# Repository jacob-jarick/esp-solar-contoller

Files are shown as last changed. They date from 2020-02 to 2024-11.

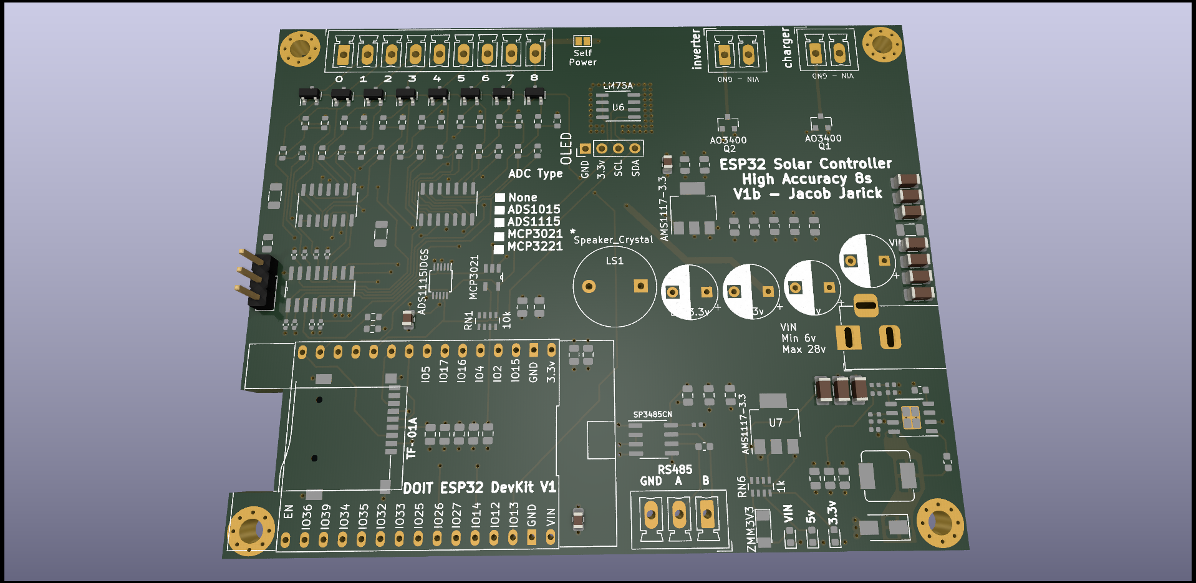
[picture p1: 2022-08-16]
esp32 board.png

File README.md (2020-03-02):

# esp-solar-contoller

esp8266 and esp32 based solar controllers targetting Houses with a fronius solar system (other inverters can be supported).

Inspired by the various DIY powerwalls

https://www.facebook.com/groups/diypowerwalls/

## Use

Common Day devices:

* Pool Pump
* powerwall / UPS / Battery Bank charger
* roof exhuast fan

Common Night time Devices:

* UPS mains disconnect
* Grid tie inverter turn on

## Example Applications

**Simple**

(day) Turn on day time device when PV export is greater than device size (eg pool pump)

**DIY Powerwall**

(Day) Turn on charger when PV export is greater than charger size.

(night) Turn on inverter when power import is larger than inverter size.

**UPS**

(Day) Turn on charger when PV export is greater than charger size.

(night) disconnect UPS mains if house is drawing power from the grid.

## Features

* Self hosted solution, no external servers needed everything runs on the microchip.
* Complete Web Interface for confguration and monitoring.
* JSON config file for easy manual editing.
* OLED display
* Support querying Fronius inverters directly
* NTP time sync
* Fallback WiFi network settings.

### Battery Monitoring (esp32)

* High voltage disconect (day)
* Low Cell Voltage disconnect (night)
* High temp shutdown

## esp8266

Supporrt for all common esp8266 boards.

* sonoff
* IoT Yunshun
* Anything tasmota runs on.

Supports adding OLED display the above.

## ESP32 Board

Custom designed board.

* 16 Bit 4 channel ADC fed to 4 8x analog signal multiplexers allowing for a total of 32 analog lines.

* 16 Voltage monitoring lines.
* 16 ntc temp sensors + 1 ambient temp sensor.
* SD Card for config storage.
* Simple Oled display.
* Piezo buzzer.
* 5v & 3.3v i2c headers for expansion.

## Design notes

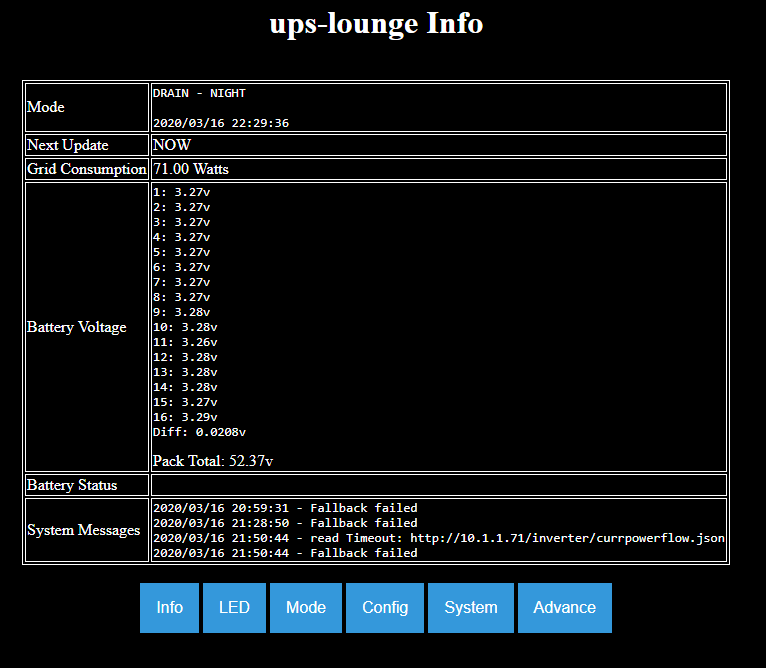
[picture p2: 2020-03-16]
pictures/stats.PNG

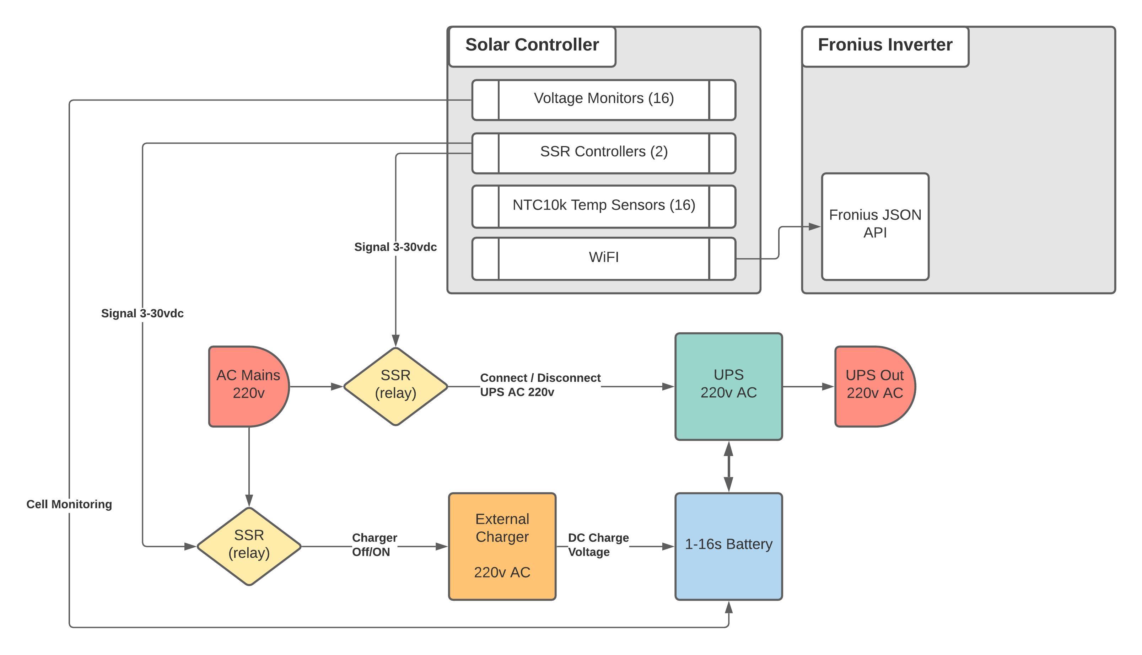
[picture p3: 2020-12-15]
docs/Solar Controller - UPS.png

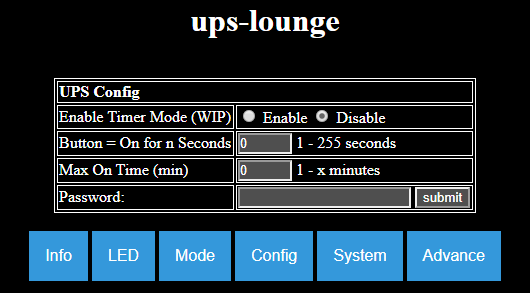
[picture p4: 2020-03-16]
pictures/timer config.PNG

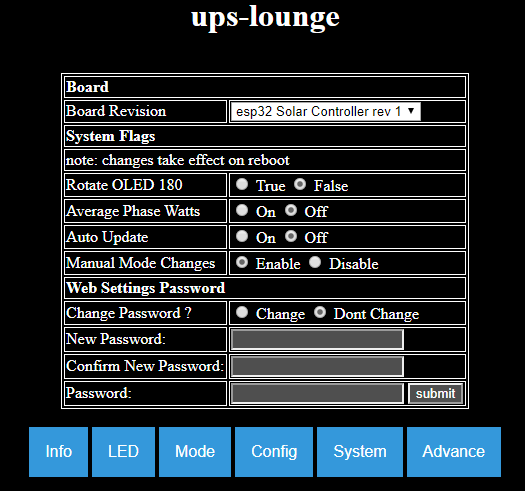
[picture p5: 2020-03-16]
pictures/system config.PNG

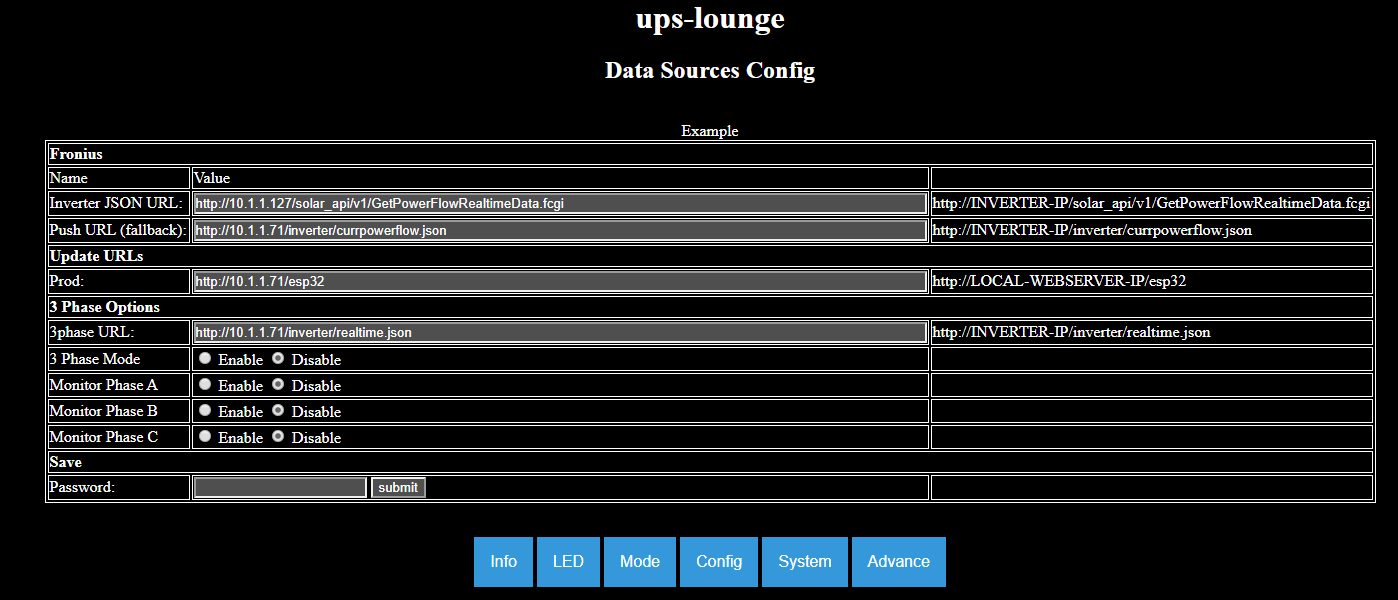
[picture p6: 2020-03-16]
pictures/data sources config.PNG

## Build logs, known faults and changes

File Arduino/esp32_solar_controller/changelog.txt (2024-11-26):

     HEAD~0	0477866 containsKey
     HEAD~1	7890894 removed jsonsize
     HEAD~2	e542fd9 no longer using DynamicJsonDocument
     HEAD~3	619b934 beep fixed !
     HEAD~4	3cfe7eb WIP
     HEAD~5	72b58d7 Updating to boards library 3.0
     HEAD~6	6bced2e migrate to board libs 3.0
     HEAD~7	af7de4d updated ansible stuff
     HEAD~8	767b9e8 Update jsonhost.yaml
     HEAD~9	dbcf0e7 esp32 board fw update, html fix
    HEAD~10	cb4bff7 HASS stuff
    HEAD~11	57f0b29 Merge branch 'master' of https://github.com/jacob-jarick/esp-solar-contoller
    HEAD~12	f5a5de1 more automation
    HEAD~13	b6dcd12 expose pin mode in api
    HEAD~14	d88c020 Update configuration.yaml
    HEAD~15	5f34a1a Update configuration.yaml
    HEAD~16	f50d760 Create JSONPath Expression Tester.url
    HEAD~17	27d5b2b Update configuration.yaml
    HEAD~18	b6071d5 added switch for HASS
    HEAD~19	deb101d home automation stuff

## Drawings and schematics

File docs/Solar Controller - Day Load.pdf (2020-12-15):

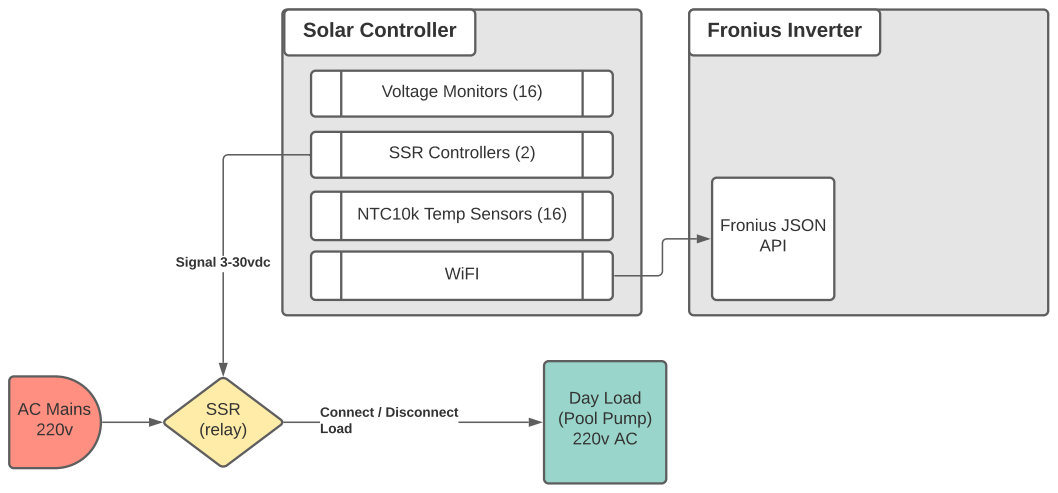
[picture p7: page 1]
Day Load (Pool Pump) 220v AC; SSR (relay); Fronius JSON API; Signal 3-30vdc; Connect / Disconnect Load; AC Mains 220v; Solar Controller; Voltage Monitors (16); SSR Controllers (2); NTC10k Temp Sensors (16); WiFI; Fronius Inverter

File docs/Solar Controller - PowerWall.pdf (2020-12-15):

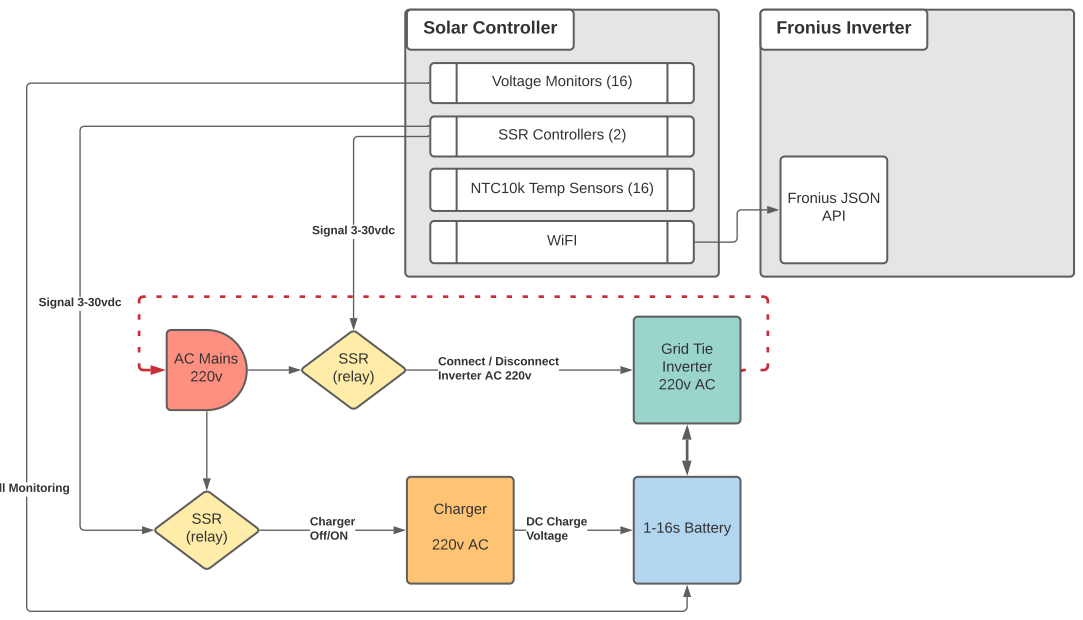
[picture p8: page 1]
Grid Tie Inverter 220v AC; SSR (relay); Fronius JSON API; Charger; 1-16s Battery; Signal 3-30vdc; DC Charge Voltage; Connect / Disconnect Inverter AC 220v; AC Mains 220v; Cell Monitoring; Solar Controller; Voltage Monitors (16); SSR Controllers (2); NTC10k Temp Sensors (16); WiFI; Fronius Inverter

Charger Off/ON

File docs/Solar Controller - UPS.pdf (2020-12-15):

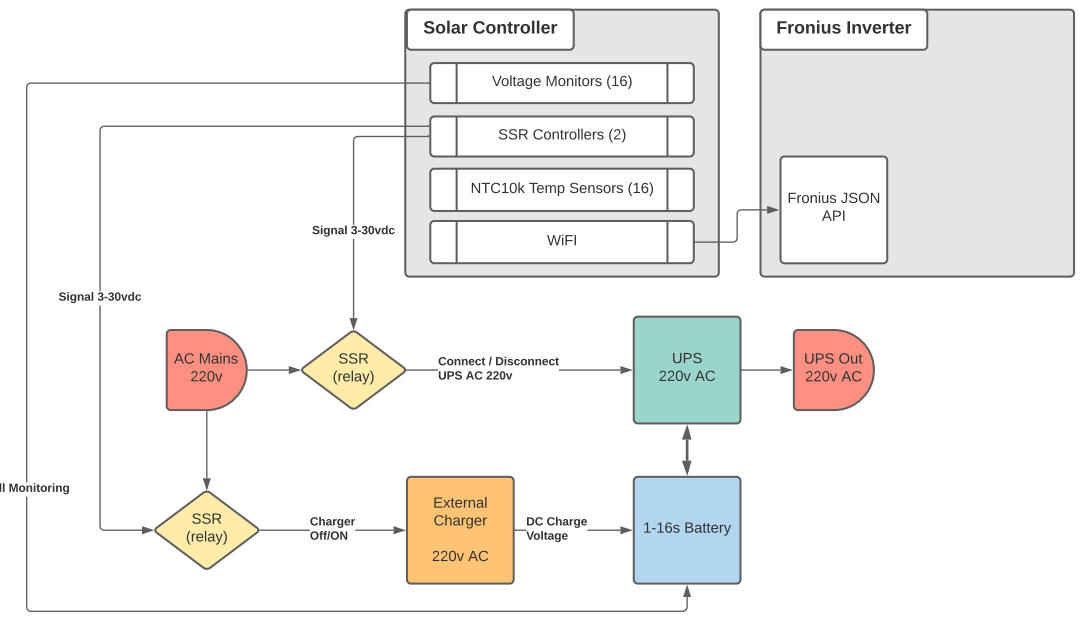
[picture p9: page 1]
UPS 220v AC; SSR (relay); Fronius JSON API; External Charger; 1-16s Battery; Signal 3-30vdc; DC Charge Voltage; Connect / Disconnect UPS AC 220v; AC Mains 220v; Cell Monitoring; UPS Out 220v AC; Solar Controller; Voltage Monitors (16); SSR Controllers (2); NTC10k Temp Sensors (16); WiFI; Fronius Inverter

Charger Off/ON

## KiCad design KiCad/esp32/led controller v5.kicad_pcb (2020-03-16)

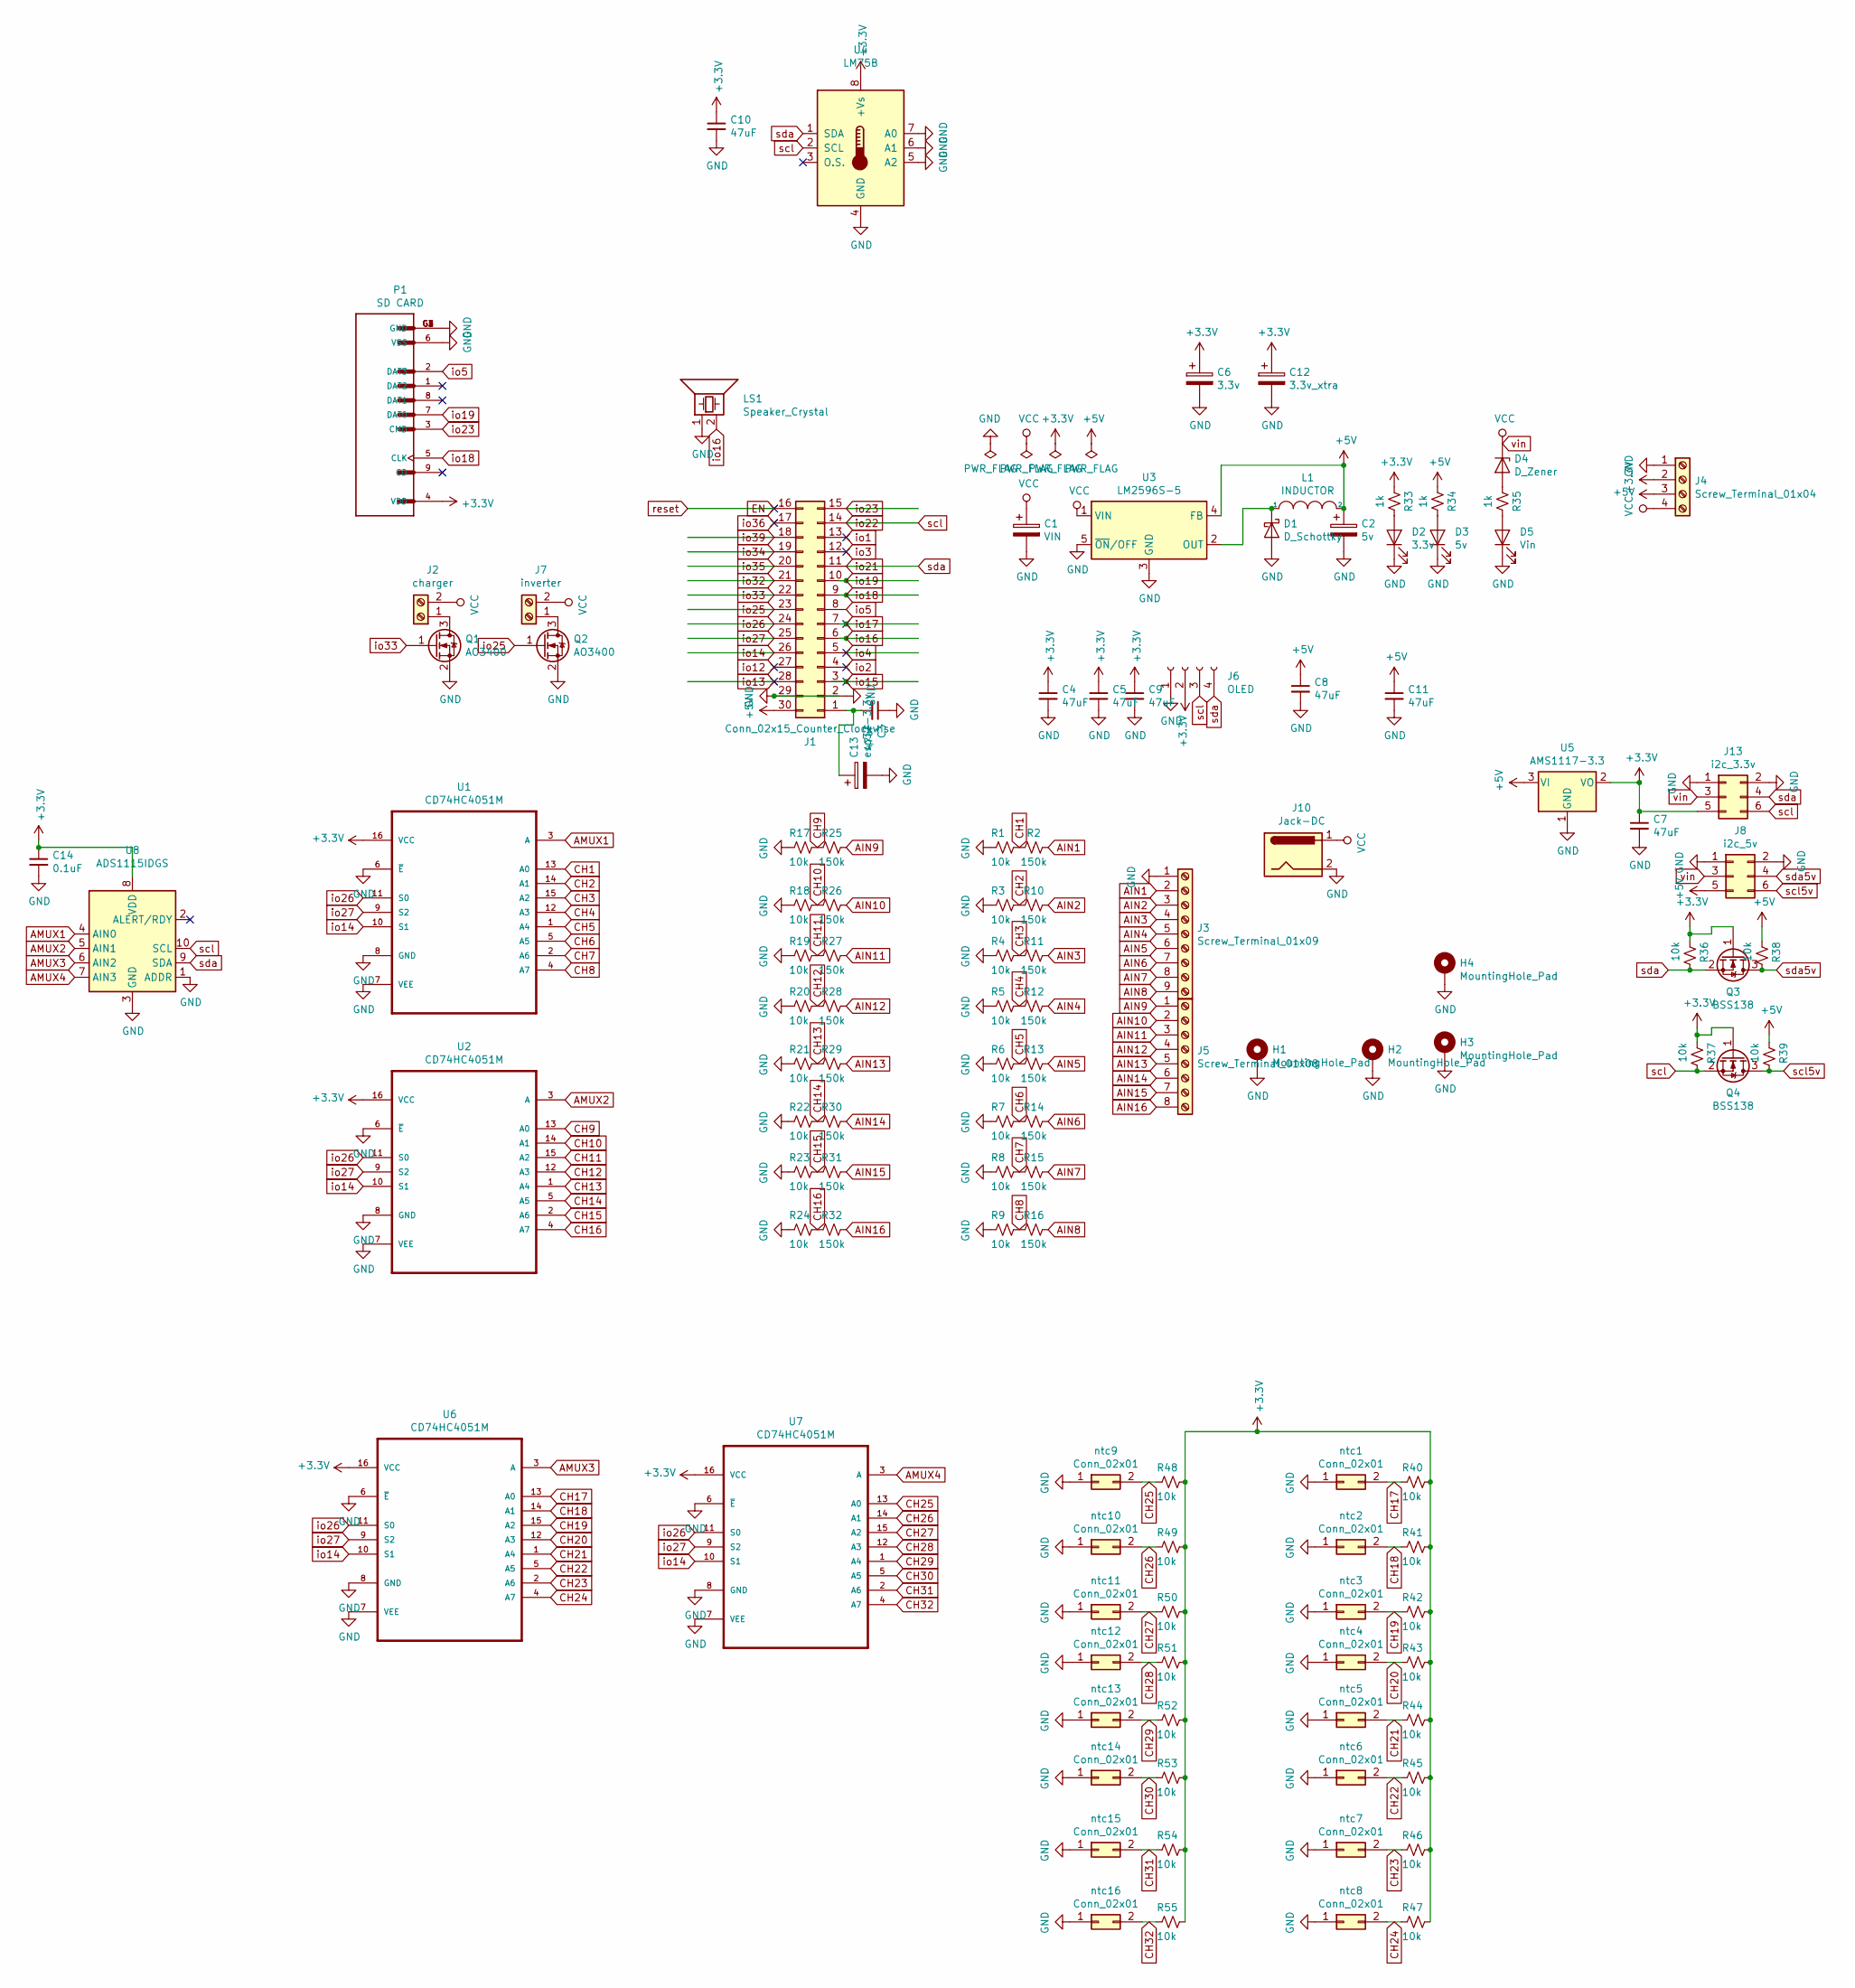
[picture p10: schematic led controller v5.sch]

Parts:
C1: VIN; CP_Radial_D10.0mm_P7.50mm
C2: 5v; CP_Radial_D10.0mm_P7.50mm
C3, C4, C5, C7, C8, C9, C10, C11: 47uF; C_0805_2012Metric_Pad1.15x1.40mm_HandSolder
C6: 3.3v; CP_Radial_D10.0mm_P7.50mm
C12: 3.3v_xtra; CP_Radial_D10.0mm_P7.50mm
C13: esp32-3.3v; CP_Radial_D10.0mm_P7.50mm
C14: 0.1uF; C_0805_2012Metric_Pad1.15x1.40mm_HandSolder
D1: D_Schottky; D_SMA_Handsoldering
D2: 3.3v; LED_1206_3216Metric_Pad1.42x1.75mm_HandSolder
D3: 5v; LED_1206_3216Metric_Pad1.42x1.75mm_HandSolder
D4: D_Zener; D_SOD-323F
D5: Vin; LED_1206_3216Metric_Pad1.42x1.75mm_HandSolder
H1, H2, H3, H4: MountingHole_Pad; MountingHole_3.2mm_M3_Pad_Via
J1: Conn_02x15_Counter_Clockwise; esp32-devkit-v1
J2: charger; PhoenixContact_MCV_1,5_2-G-3.81_1x02_P3.81mm_Vertical
J3: Screw_Terminal_01x09; PhoenixContact_MCV_1,5_9-G-3.81_1x09_P3.81mm_Vertical
J4: Screw_Terminal_01x04; PhoenixContact_MCV_1,5_4-G-3.81_1x04_P3.81mm_Vertical
J5: Screw_Terminal_01x08; PhoenixContact_MCV_1,5_8-G-3.81_1x08_P3.81mm_Vertical
J6: OLED; PinHeader_1x04_P2.54mm_Vertical
J7: inverter; PhoenixContact_MCV_1,5_2-G-3.81_1x02_P3.81mm_Vertical
J8: i2c_5v; i2c-Header-5v
J10: Jack-DC; BarrelJack_Horizontal
J13: i2c_3.3v; i2c-Header
L1: INDUCTOR; L_Taiyo-Yuden_MD-5050
LS1: Speaker_Crystal; Buzzer_15x7.5RM7.6
P1: SD CARD; SUNTECH_ST-TF-003A
Q1, Q2: AO3400; SOT-23
Q3, Q4: BSS138; SOT-23
R1, R3, R4, R5, R6, R7, R8, R9, R17, R18, R19, R20, R21, R22, R23, R24, R36, R37, R38, R39, R40, R41, R42, R43, R44, R45, R46, R47, R48, R49, R50, R51, R52, R53, R54, R55: 10k; R_0805_2012Metric_Pad1.15x1.40mm_HandSolder
R2, R10, R11, R12, R13, R14, R15, R16, R25, R26, R27, R28, R29, R30, R31, R32: 150k; R_0805_2012Metric_Pad1.15x1.40mm_HandSolder
R33, R34, R35: 1k; R_0805_2012Metric_Pad1.15x1.40mm_HandSolder
U1, U2, U6, U7: CD74HC4051M; STC_SOP-16_3.9x9.9mm_P1.27mm
U3: LM2596S-5; TO-263-5_TabPin3
U4: LM75B; SOIC-8_3.9x4.9mm_P1.27mm
U5: AMS1117-3.3; SOT-223-3_TabPin2
U8: ADS1115IDGS; TSSOP-10_3x3mm_P0.5mm
ntc1, ntc2, ntc3, ntc4, ntc5, ntc6, ntc7, ntc8, ntc9, ntc10, ntc11, ntc12, ntc13, ntc14, ntc15, ntc16: Conn_02x01; PinHeader_1x02_P2.54mm_Vertical

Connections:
+3V3: C4.1, C5.1, C6.1, C7.1, C9.1, C10.1, C12.1, C14.1, J4.2, J6.2, J13.5, P1.4 (VDD), Q3.1 (G), Q4.1 (G), R33.1, R36.2, R37.2, R40.1, R41.1, R42.1, R43.1, R44.1, R45.1, R46.1, R47.1, R48.1, R49.1, R50.1, R51.1, R52.1, R53.1, R54.1, R55.1, U1.16 (VCC), U2.16 (VCC), U4.8 (+Vs), U5.2 (VO), U6.16 (VCC), U7.16 (VCC), U8.8 (VDD)
+5V: C2.1, C8.1, C11.1, J1.30, J4.3, J8.5, L1.2, R34.1, R38.2, R39.2, U3.4 (FB), U5.3 (VI)
AIN1: J3.2, R2.2
AIN2: J3.3, R10.2
AIN3: J3.4, R11.2
AIN4: J3.5, R12.2
AIN5: J3.6, R13.2
AIN6: J3.7, R14.2
AIN7: J3.8, R15.2
AIN8: J3.9, R16.2
AIN9: J5.1, R25.2
AIN10: J5.2, R26.2
AIN11: J5.3, R27.2
AIN12: J5.4, R28.2
AIN13: J5.5, R29.2
AIN14: J5.6, R30.2
AIN15: J5.7, R31.2
AIN16: J5.8, R32.2
AMUX1: U1.3 (A), U8.4 (AIN0)
AMUX2: U2.3 (A), U8.5 (AIN1)
AMUX3: U6.3 (A), U8.6 (AIN2)
AMUX4: U7.3 (A), U8.7 (AIN3)
CH1: R1.1, R2.1, U1.13 (A0)
CH2: R3.1, R10.1, U1.14 (A1)
CH3: R4.1, R11.1, U1.15 (A2)
CH4: R5.1, R12.1, U1.12 (A3)
CH5: R6.1, R13.1, U1.1 (A4)
CH6: R7.1, R14.1, U1.5 (A5)
CH7: R8.1, R15.1, U1.2 (A6)
CH8: R9.1, R16.1, U1.4 (A7)
CH9: R17.1, R25.1, U2.13 (A0)
CH10: R18.1, R26.1, U2.14 (A1)
CH11: R19.1, R27.1, U2.15 (A2)
CH12: R20.1, R28.1, U2.12 (A3)
CH13: R21.1, R29.1, U2.1 (A4)
CH14: R22.1, R30.1, U2.5 (A5)
CH15: R23.1, R31.1, U2.2 (A6)
CH16: R24.1, R32.1, U2.4 (A7)
CH17: R40.2, U6.13 (A0), ntc1.2
CH18: R41.2, U6.14 (A1), ntc2.2
CH19: R42.2, U6.15 (A2), ntc3.2
CH20: R43.2, U6.12 (A3), ntc4.2
CH21: R44.2, U6.1 (A4), ntc5.2
CH22: R45.2, U6.5 (A5), ntc6.2
CH23: R46.2, U6.2 (A6), ntc7.2
CH24: R47.2, U6.4 (A7), ntc8.2
CH25: R48.2, U7.13 (A0), ntc9.2
CH26: R49.2, U7.14 (A1), ntc10.2
CH27: R50.2, U7.15 (A2), ntc11.2
CH28: R51.2, U7.12 (A3), ntc12.2
CH29: R52.2, U7.1 (A4), ntc13.2
CH30: R53.2, U7.5 (A5), ntc14.2
CH31: R54.2, U7.2 (A6), ntc15.2
CH32: R55.2, U7.4 (A7), ntc16.2
EN: J1.16
GND: C1.2, C2.2, C3.1, C4.2, C5.2, C6.2, C7.2, C8.2, C9.2, C10.2, C11.2, C12.2, C13.2, C14.2, D1.2 (A), D2.1 (K), D3.1 (K), D5.1 (K), H1.1, H2.1, H3.1, H4.1, J1.2, J1.29, J3.1, J4.1, J6.1, J8.1, J8.2, J10.2, J13.1, J13.2, LS1.1, P1.6 (VSS), P1.G1 (GND), P1.G2 (GND), P1.G3 (GND), P1.G4 (GND), Q1.2 (S), Q2.2 (S), R1.2, R3.2, R4.2, R5.2, R6.2, R7.2, R8.2, R9.2, R17.2, R18.2, R19.2, R20.2, R21.2, R22.2, R23.2, R24.2, U1.6 (~E), U1.7 (VEE), U1.8 (GND), U2.6 (~E), U2.7 (VEE), U2.8 (GND), U3.3 (GND), U3.5 (~ON~/OFF), U4.4 (GND), U4.5 (A2), U4.6 (A1), U4.7 (A0), U5.1 (GND), U6.6 (~E), U6.7 (VEE), U6.8 (GND), U7.6 (~E), U7.7 (VEE), U7.8 (GND), U8.1 (ADDR), U8.3 (GND), ntc1.1, ntc2.1, ntc3.1, ntc4.1, ntc5.1, ntc6.1, ntc7.1, ntc8.1, ntc9.1, ntc10.1, ntc11.1, ntc12.1, ntc13.1, ntc14.1, ntc15.1, ntc16.1
unnamed: C3.2, C13.1, J1.1
unnamed: D1.1 (K), L1.1, U3.2 (OUT)
unnamed: D2.2 (A), R33.2
unnamed: D3.2 (A), R34.2
unnamed: D4.2 (A), R35.1
unnamed: D5.2 (A), R35.2
unnamed: J2.1, Q1.3 (D)
unnamed: J7.1, Q2.3 (D)
io1: J1.13
io2: J1.4
io3: J1.12
io4: J1.5
io5: J1.8, P1.2 (DAT3)
io12: J1.27
io13: J1.28
io14: J1.26, U1.10 (S1), U2.10 (S1), U6.10 (S1), U7.10 (S1)
io15: J1.3
io16: J1.6, LS1.2
io17: J1.7
io18: J1.9, P1.5 (CLK)
io19: J1.10, P1.7 (DAT0)
io21: J1.11, J6.4, J13.4, Q3.2 (S), R36.1, U4.1 (SDA), U8.9 (SDA)
io22: J1.14, J6.3, J13.6, Q4.2 (S), R37.1, U4.2 (SCL), U8.10 (SCL)
io23: J1.15, P1.3 (CMD)
io25: J1.23, Q2.1 (G)
io26: J1.24, U1.11 (S0), U2.11 (S0), U6.11 (S0), U7.11 (S0)
io27: J1.25, U1.9 (S2), U2.9 (S2), U6.9 (S2), U7.9 (S2)
io32: J1.21
io33: J1.22, Q1.1 (G)
io34: J1.19
io35: J1.20
io36: J1.17
io39: J1.18
scl5v: J8.6, Q4.3 (D), R39.1
sda5v: J8.4, Q3.3 (D), R38.1
vin: C1.1, D4.1 (K), J2.2, J4.4, J7.2, J8.3, J10.1, J13.3, U3.1 (VIN)

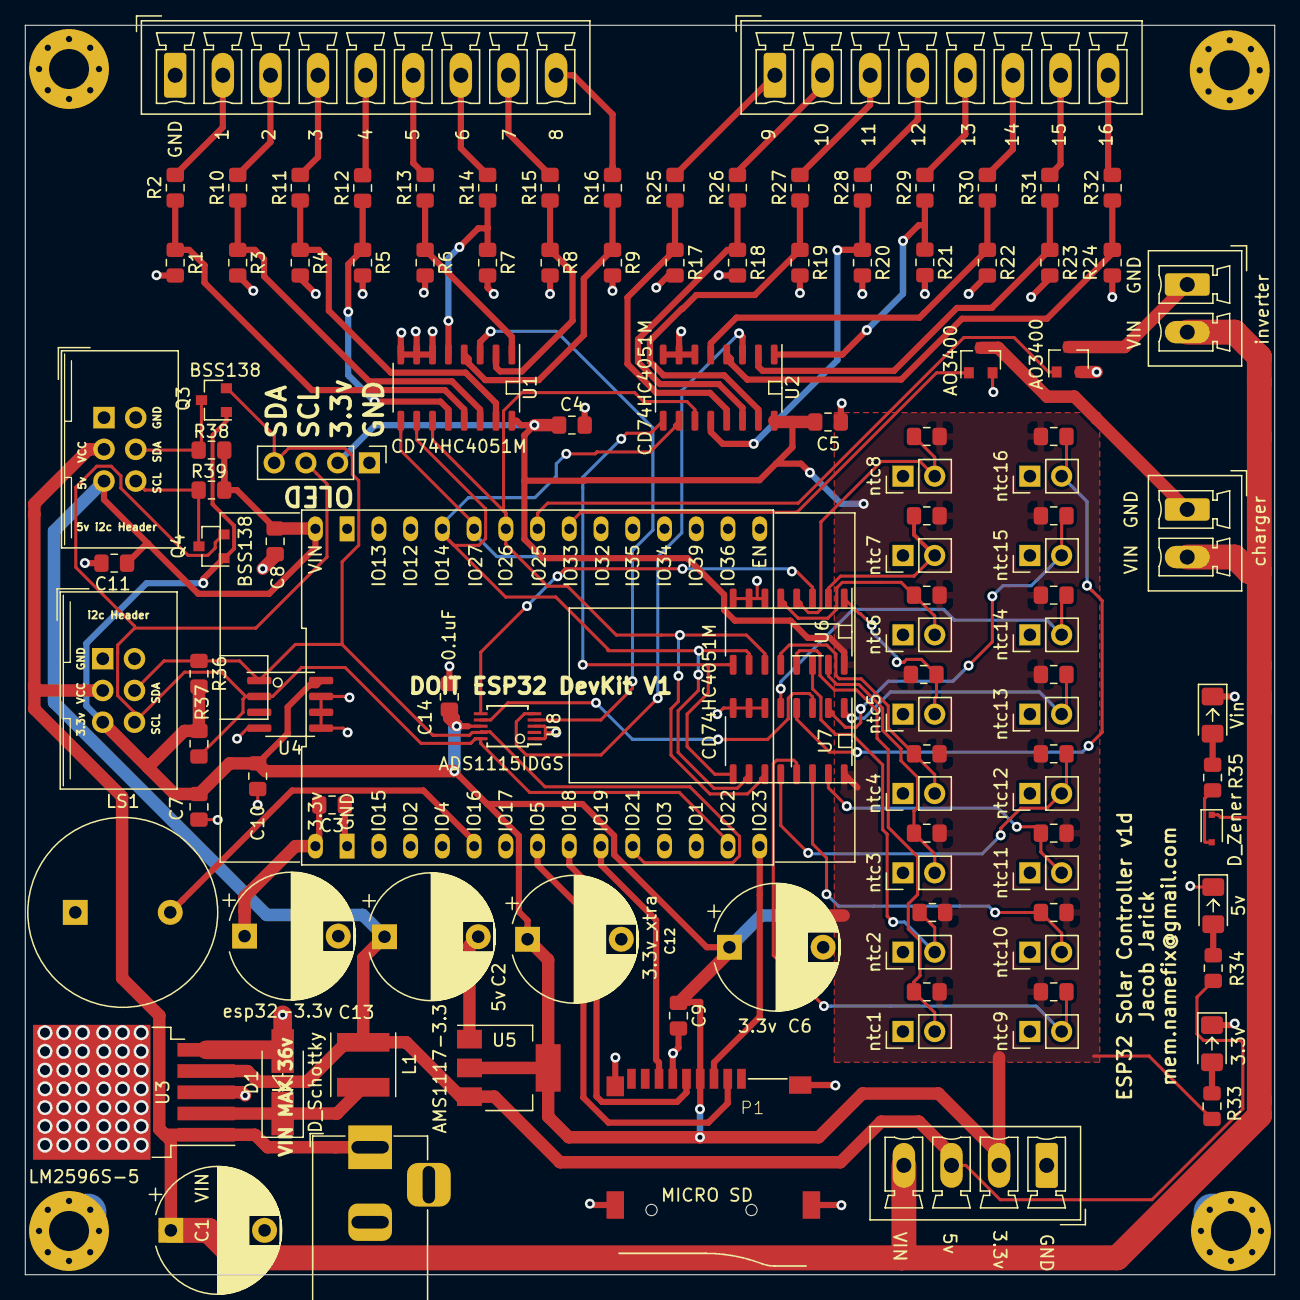
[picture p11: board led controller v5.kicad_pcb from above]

Board: 2 copper layers, 100.0 x 100.0 mm, 119 parts (0 on the bottom side), 78 nets.

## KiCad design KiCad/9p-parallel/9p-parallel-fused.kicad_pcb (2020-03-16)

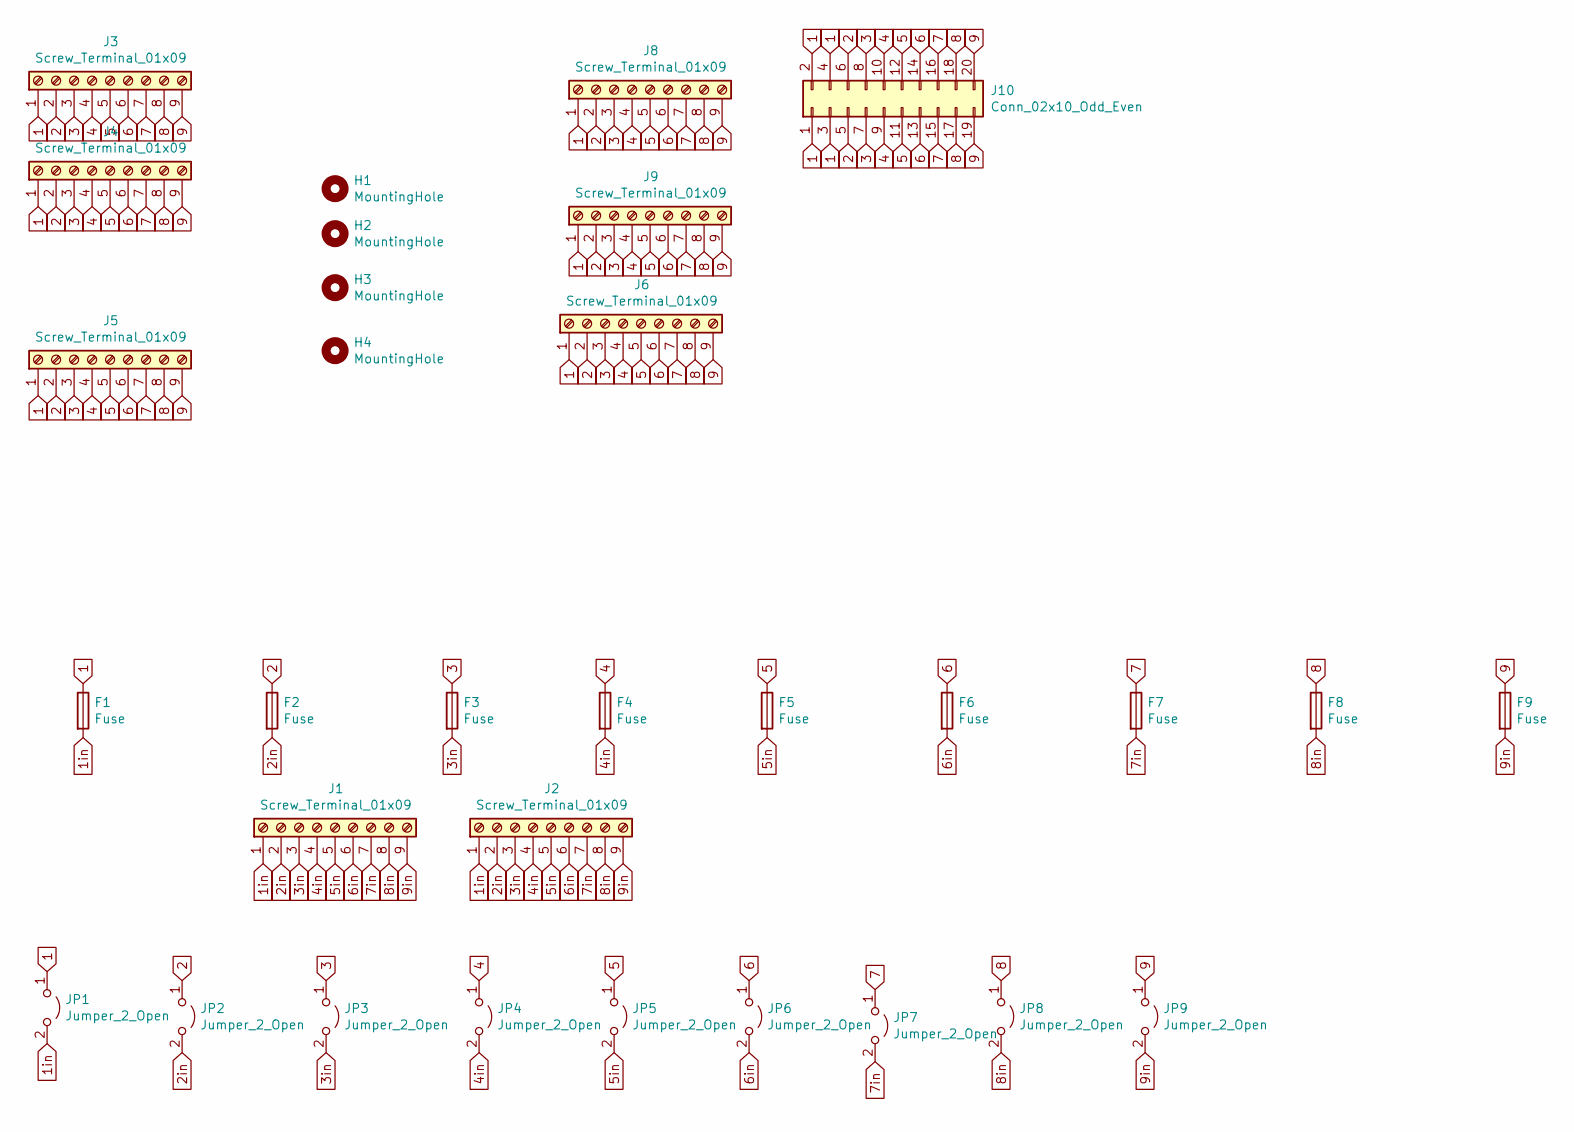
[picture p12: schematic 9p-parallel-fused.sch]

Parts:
F1, F2, F3, F4, F5, F6, F7, F8, F9: Fuse; Fuseholder_Cylinder-5x20mm_Stelvio-Kontek_PTF78_Horizontal_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
H1, H2, H3, H4: MountingHole; MountingHole_4.3mm_M4_ISO14580
J1: Screw_Terminal_01x09; PhoenixContact_MC_1,5_9-G-5.08_1x09_P5.08mm_Horizontal-larg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
J2, J6, J8, J9: Screw_Terminal_01x09; PhoenixContact_MCV_1,5_9-G-3.81_1x09_P3.81mm_Vertical
J3, J4, J5: Screw_Terminal_01x09; PhoenixContact_MCV_1,5_9-G-5.08_1x09_P5.08mm_Vertical-large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
J10: Conn_02x10_Odd_Even; IDC-Header_2x10_P2.54mm_Vertical
JP1, JP2, JP3, JP4, JP5, JP6, JP7, JP8, JP9: Jumper_2_Open; SolderJumper-2_P1.3mm_Open_Pad1.0x1.5mm

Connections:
1: F1.1, J3.1, J4.1, J5.1, J6.1, J8.1, J9.1, J10.1, J10.2, J10.3, J10.4, JP1.1 (A)
1in: F1.2, J1.1, J2.1, JP1.2 (B)
2: F2.1, J3.2, J4.2, J5.2, J6.2, J8.2, J9.2, J10.5, J10.6, JP2.1 (A)
2in: F2.2, J1.2, J2.2, JP2.2 (B)
3: F3.1, J3.3, J4.3, J5.3, J6.3, J8.3, J9.3, J10.7, J10.8, JP3.1 (A)
3in: F3.2, J1.3, J2.3, JP3.2 (B)
4: F4.1, J3.4, J4.4, J5.4, J6.4, J8.4, J9.4, J10.9, J10.10, JP4.1 (A)
4in: F4.2, J1.4, J2.4, JP4.2 (B)
5: F5.1, J3.5, J4.5, J5.5, J6.5, J8.5, J9.5, J10.11, J10.12, JP5.1 (A)
5in: F5.2, J1.5, J2.5, JP5.2 (B)
6: F6.1, J3.6, J4.6, J5.6, J6.6, J8.6, J9.6, J10.13, J10.14, JP6.1 (A)
6in: F6.2, J1.6, J2.6, JP6.2 (B)
7: F7.1, J3.7, J4.7, J5.7, J6.7, J8.7, J9.7, J10.15, J10.16, JP7.1 (A)
7in: F7.2, J1.7, J2.7, JP7.2 (B)
8: F8.1, J3.8, J4.8, J5.8, J6.8, J8.8, J9.8, J10.17, J10.18, JP8.1 (A)
8in: F8.2, J1.8, J2.8, JP8.2 (B)
9: F9.1, J3.9, J4.9, J5.9, J6.9, J8.9, J9.9, J10.19, J10.20, JP9.1 (A)
9in: F9.2, J1.9, J2.9, JP9.2 (B)

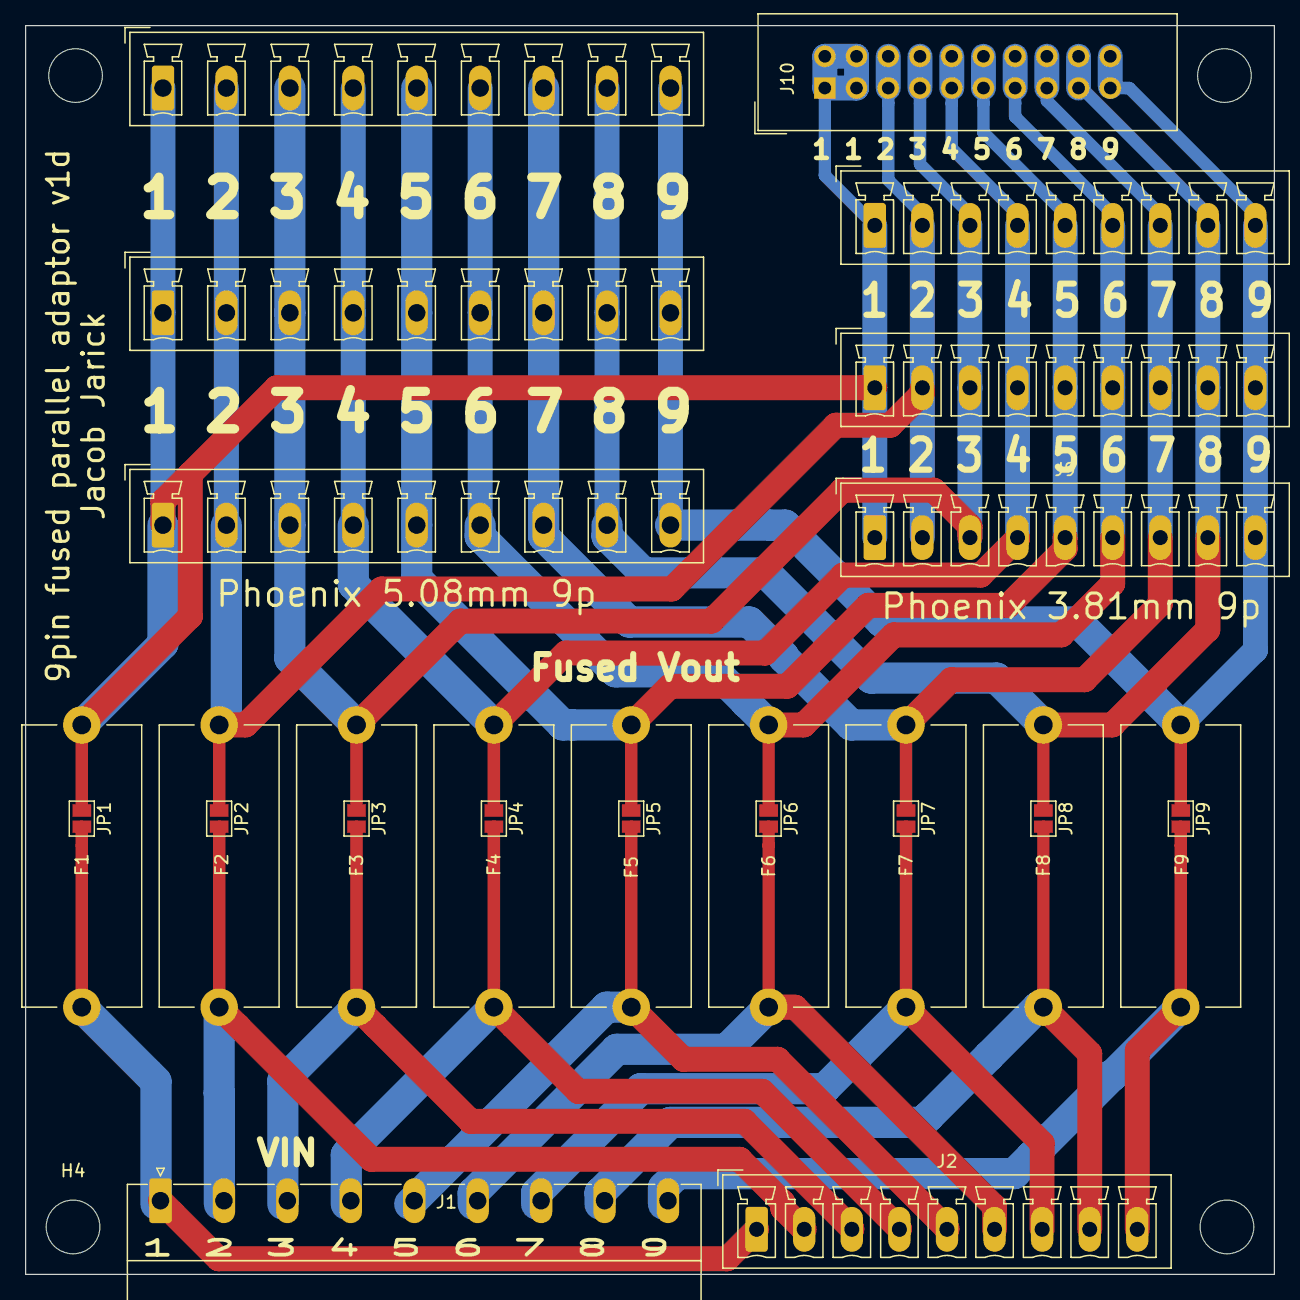
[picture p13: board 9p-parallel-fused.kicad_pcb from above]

Board: 2 copper layers, 100.0 x 100.0 mm, 31 parts (0 on the bottom side), 18 nets.

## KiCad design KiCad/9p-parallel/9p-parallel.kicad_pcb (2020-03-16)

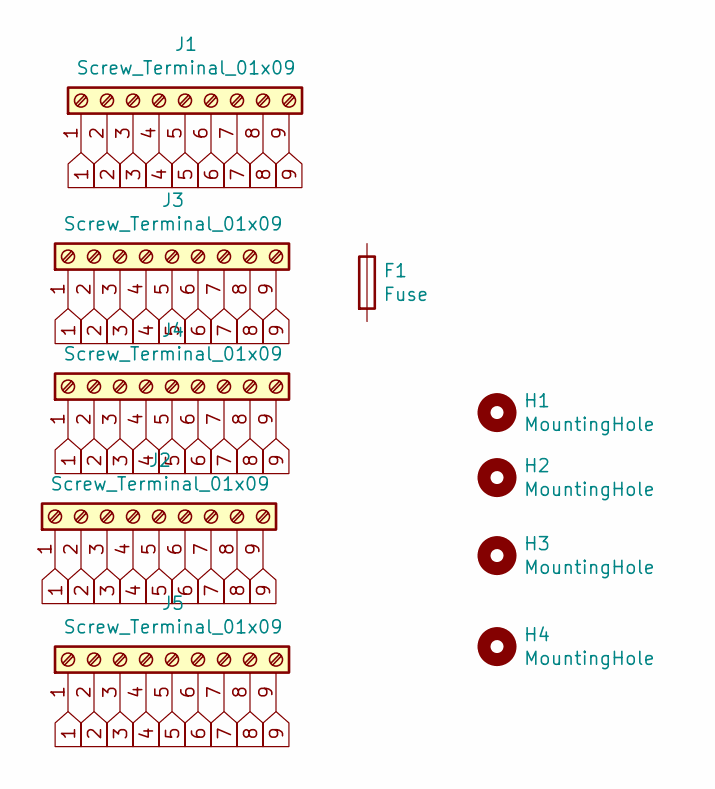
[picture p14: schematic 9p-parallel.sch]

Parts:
F1: Fuse; Fuseholder_Cylinder-5x20mm_Stelvio-Kontek_PTF78_Horizontal_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
H1, H2, H3, H4: MountingHole; MountingHole_4.3mm_M4_ISO14580
J1: Screw_Terminal_01x09; PhoenixContact_MC_1,5_9-G-5.08_1x09_P5.08mm_Horizontal
J2, J3, J4, J5: Screw_Terminal_01x09; PhoenixContact_MCV_1,5_9-G-5.08_1x09_P5.08mm_Vertical

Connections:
1: J1.1, J2.1, J3.1, J4.1, J5.1
2: J1.2, J2.2, J3.2, J4.2, J5.2
3: J1.3, J2.3, J3.3, J4.3, J5.3
4: J1.4, J2.4, J3.4, J4.4, J5.4
5: J1.5, J2.5, J3.5, J4.5, J5.5
6: J1.6, J2.6, J3.6, J4.6, J5.6
7: J1.7, J2.7, J3.7, J4.7, J5.7
8: J1.8, J2.8, J3.8, J4.8, J5.8
9: J1.9, J2.9, J3.9, J4.9, J5.9

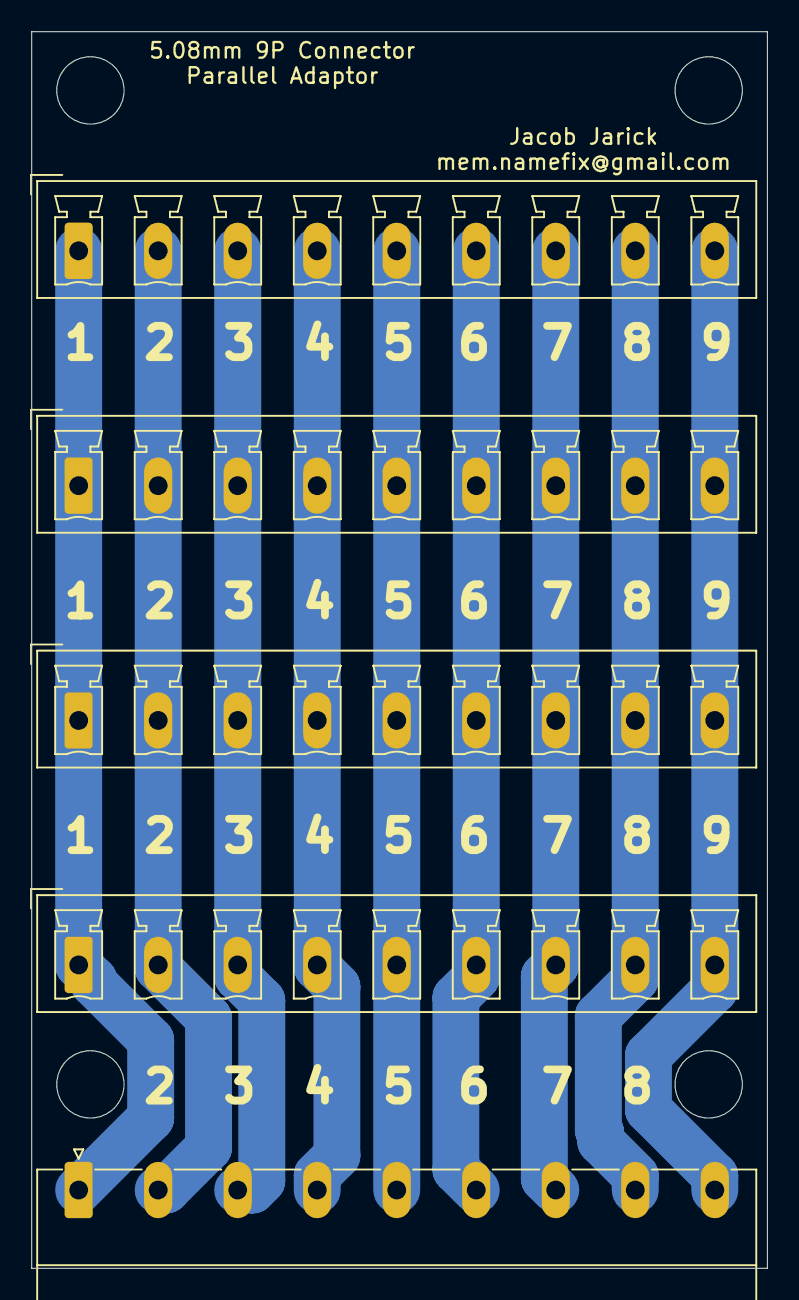
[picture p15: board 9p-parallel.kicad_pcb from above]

Board: 2 copper layers, 47.0 x 79.0 mm, 9 parts (0 on the bottom side), 9 nets.

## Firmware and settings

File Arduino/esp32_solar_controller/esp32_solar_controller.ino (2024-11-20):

/*

Note I use esp32 doit dev kit v1.
but the arduino IDE settings for this board seem to cause issues.

so I configure the IDE to use:

* WEMOS LOLIN32
* Patition Scheme: Minimal SPIFFS, large app with OTA
* CPU 240Mhz (WiFi/BT)
* Flash Frequency 80Mhz

this seems to resolve OTA issues.

*/

#define FW_VERSION 406

// to longer timeout = esp weirdness
#define httpget_timeout 5000

#define OPT_DISABLE -2
#define OPT_DEFAULT -1

#define stiny 32
#define ssmall 64
#define smedium 128
#define slarge 257

#define MAX_CELLS 16


// ================================================================================================
/*
 *  Print last reset reason of ESP32
 *  =================================
 *
 *  Use either of the methods print_reset_reason
 *  or verbose_print_reset_reason to display the
 *  cause for the last reset of this device.
 *
 *  Public Domain License.
 *
 *  Author:
 *  Evandro Luis Copercini - 2017
 */

#if CONFIG_IDF_TARGET_ESP32  // ESP32/PICO-D4
#include "esp32/rom/rtc.h"
#elif CONFIG_IDF_TARGET_ESP32S2
#include "esp32s2/rom/rtc.h"
#elif CONFIG_IDF_TARGET_ESP32C2
#include "esp32c2/rom/rtc.h"
#elif CONFIG_IDF_TARGET_ESP32C3
#include "esp32c3/rom/rtc.h"
#elif CONFIG_IDF_TARGET_ESP32S3
#include "esp32s3/rom/rtc.h"
#elif CONFIG_IDF_TARGET_ESP32C6
#include "esp32c6/rom/rtc.h"
#elif CONFIG_IDF_TARGET_ESP32H2
#include "esp32h2/rom/rtc.h"
#else
#error Target CONFIG_IDF_TARGET is not supported
#endif

#define uS_TO_S_FACTOR 1000000 /* Conversion factor for micro seconds to seconds */

// ================================================================================================

// #include <Arduino.h>
#include <SD.h>

#include <WiFi.h>
#include <WiFiClient.h>
#include <WiFiAP.h> // todo remove as WiFi is configured via SD card json config
#include <WiFiUdp.h>
#include <ESPmDNS.h>

#include <HTTPClient.h>

#include <ESP32httpUpdate.h>

#include <ArduinoJson.h>

#include <WebServer.h>
WebServer server(80);

// -----------------------------------------------------------------------------------------

#include <Wire.h>
#include "SSD1306Ascii.h"
#include "SSD1306AsciiWire.h"

SSD1306AsciiWire oled;

// -----------------------------------------------------------------------------------------

#include <Ads1115_mux.h>
const uint8_t pin_asel1 = 26;
const uint8_t pin_asel2 = 17;
const uint8_t pin_asel3 = 14;
const uint8_t pin_asel4 = 27;

Ads1115_mux adsmux(pin_asel1, pin_asel2, pin_asel3, pin_asel4);

// -----------------------------------------------------------------------------------------

const uint8_t pin_buzzer = 16;

// -----------------------------------------------------------------------------------------
// lm75a

// note: modify library and comment out wire.begin and wire.end

#include <M2M_LM75A.h>
M2M_LM75A lm75a(0x4f);
M2M_LM75A lm75a2(0x48); // used on micro boards

uint8_t lm75a_address = 0x4f;

float board_temp = 0;
float board_temp_min = 9999999;
float board_temp_max = 0;
float board_temp_old = 0; // only used to track changes in temp to prevent message spam.

// -----------------------------------------------------------------------------------------

#include <Mmaths.h>

Mmaths mmaths;

// -----------------------------------------------------------------------------------------

#include <TimeLib.h>

const unsigned int localPort = 2390;      // local port to listen for UDP packets

const int NTP_PACKET_SIZE = 48; // NTP time is in the first 48 bytes of message
byte packetBuffer[NTP_PACKET_SIZE]; //buffer to hold incoming & outgoing packets

WiFiUDP Udp;

// -----------------------------------------------------------------------------------------
// timers

struct SysTimers
{
  unsigned long api = 0;
  unsigned long iapi = 0;
  unsigned long api_last_update = 0;

  unsigned long mode_check = 0;
  unsigned long pgrid_last_update = 0;
  unsigned long use_fallback = 0;

  unsigned long lv_shutdown = 0;
  unsigned long hv_shutdown = 0;

  unsigned long charger_off = 0;
  unsigned long inverter_off = 0;

  unsigned long pgrid = 0;
  unsigned long adc_poll = 0;
  unsigned long lm75a_poll = 0;

  unsigned long update_check = 0;
  unsigned long ntp_sync = 0;
  unsigned long oled = 0;

  unsigned long led = 0;

  unsigned long i2c_check = 0;

  unsigned long calc_energy_usage = 0;
};

SysTimers timers;

//------------------------------------------------------------------------------
// cell voltages

double cells_volts[MAX_CELLS*3];
double cells_volts_real[MAX_CELLS*3]; // used to track real voltage when using AIN, used as temp storage for API
float cell_volt_diff = 0;
float cell_volt_high = 0;
float cell_volt_low = 0;

float pack_total_volts = 0;

// uint8_t cell_lh[2] = {0, 0};
uint8_t low_cell = 0;
uint8_t high_cell = 0;

//------------------------------------------------------------------------------

uint8_t vapi_errors = 0;

//------------------------------------------------------------------------------

const String mime_html    = "text/html";
const String mime_txt     = "text/plain";
const String mime_json    = "application/json";
const String mime_css     = "text/css";

const String http_str     = "http://";
const String denied_str   = "Denied";
const String title_str    = "title_hostn";

const String dothtml        = ".htm";
const String dottxt        = ".txt";

const String html_header          = "/header" + dothtml;
const String html_config          = "/config" + dothtml;
const String html_battery         = "/batconf" + dothtml;
const String html_calibrate       = "/batcal" + dothtml;
const String html_acinfo          = "/acinfo" + dothtml;
const String html_cpconfig        = "/cpconfig" + dothtml;
const String html_stats           = "/stats" + dothtml;
const String html_mode            = "/mode" + dothtml;
const String html_modet            = "/modet" + dothtml;
const String html_apiservers      = "/api" + dothtml;
const String html_advance_config  = "/advance" + dothtml;
const String html_footer          = "/footer" + dothtml;
const String html_js_header       = "/jsheader" + dothtml;
const String html_issue_log       = "/issue" + dothtml;
const String html_net_config      = "/network" + dothtml;
const String html_datasrcs        = "/datasrcs" + dothtml;
const String html_sys_info        = "/system" + dothtml;
const String html_battery_info    = "/battery" + dothtml;
const String html_upload_config   = "/up_conf" + dothtml;
const String html_port_config     = "/portconf" + dothtml;

const String css_file             = "/style.css";
const String txt_log_system       = "/log" + dottxt;
const String txt_passwd_file      = "/passwd";
const String json_config_file     = "/config.jsn";

//------------------------------------------------------------------------------

const uint16_t size_system_msgs = 1024;
String system_msgs = "";



float phase_a_watts = 0;
float phase_b_watts = 0;
float phase_c_watts = 0;

float phase_a_voltage = 0;
float phase_b_voltage = 0;
float phase_c_voltage = 0;

float phase_a_voltage_high = 0;
float phase_b_voltage_high = 0;
float phase_c_voltage_high = 0;

float phase_a_voltage_low = 10000;
float phase_b_voltage_low = 10000;
float phase_c_voltage_low = 10000;


float energy_consumed_old = 0; // previous day
float energy_consumed = 0;

float phase_sum = 0;
float phase_sum_old = 0;

float phase_avg = 0;

String passwd = "";

uint8_t download_index = 0; // html page download index
byte system_mode = 0;

uint8_t i2cdevcount = 0; // used on startup and then for system i2c ping

const int8_t power_array_size = 10;

int get_url_code; // global url fetch code, eg 404, 401, 200

// =================================================================================================


//------------------------------------------------------------------------------

const uint8_t max_api_vservers = 3;
const uint8_t max_api_iservers = 1;

struct Sconfig
{
  uint16_t fwver = 0;

  float maxsystemtemp = 40;


  // API

  uint8_t api_vserver_count = 0;


  bool api_venable[max_api_vservers];
  char api_vserver_hostname[max_api_vservers][ssmall];

  bool api_ienable[max_api_iservers];
  char api_iserver_hostname[max_api_iservers][ssmall];

  bool api_lm75a = 0;
  bool api_grid = 0;

  float api_pollsecs = 1;

  // END of API

  char threephase_direct_url[smedium];
  char fronius_push_url[smedium];
  char pub_url[smedium];

  // sortme

  float lv_shutdown_delay; // float because we use fraction of hours eh 0.5h
  float hv_shutdown_delay;

  uint8_t charger_oot_min;
  uint8_t charger_oot_sec;

  uint8_t charger_off_min;
  uint8_t charger_off_sec;

  uint8_t inverter_oot_min;
  uint8_t inverter_oot_sec;
  byte cell_count;
  byte gmt; // divide by 2 and minus 12
  float dcvoltage_offset;
  uint8_t board_rev;

  uint8_t i2cmaxspeed;

  // wifi

  char wifi_ssid1[ssmall];
  char wifi_pass1[ssmall];
  char wifi_ssid2[ssmall];
  char wifi_pass2[ssmall];

  double battery_volt_mod[MAX_CELLS];

  char hostn[stiny];

  int8_t pin_led;
  int8_t pin_charger;
  int8_t pin_inverter;
  int8_t pin_wd;
  int8_t pin_flash;

  int8_t pin_sda;
  int8_t pin_scl;

  char update_host[ssmall];

  char ntp_server[ssmall];

  // battery stuff

  bool monitor_battery = 0;
  float pack_volt_min;
  float battery_volt_min;
  float battery_volt_rec;
  float battery_volt_max;

  // END battery stuff

  float cpkwh; // cost per kwh

  char description[smedium];

  // device addresses

  char oled_addr;

  // bools

  bool rotate_oled = 0;
  bool blink_led = 0;
  bool blink_led_default = 0;

  bool avg_ain = 0;

  bool threephase = 0;
  bool monitor_phase_a = 0;
  bool monitor_phase_b = 0;
  bool monitor_phase_c = 0;
  bool flip_ipin = 0;
  bool flip_cpin = 0;
  bool auto_update = 0;
  bool inv_idle_mode = 0;
  bool i_enable = 0;
  bool c_enable = 0;
  bool day_is_timer = 0;
  bool night_is_timer = 0;

  bool serial_off = 0;

  bool c_offd; // charger custom off delay
  bool c_amot; // charger idle after min on time


  bool prefer_dc = 0;

  bool hv_monitor = 1;

  uint8_t display_mode = 0;

  bool m247 = 0;

  //
  int day_watts = 0;
  int night_watts = 0;

  uint8_t c_start_h = 0;
  uint8_t c_finish_h = 0;
  uint8_t i_start_h = 0;
  uint8_t i_finish_h = 0;

  uint8_t avg_phase = 0;

  bool webc_mode = 0;
  bool led_status = 0;

  bool mcptype = 0; // 0 = MCP3021, 1 = MCP3221
  bool ads1x15type = 0; // 0 = ADS1015, 1 = ADS1115
  uint8_t muxtype = 0; // 0 = old board (2* 8-1), 1 = new boards (16-1), 2 = high precision board

  bool dumbsystem = 0; // 1 dont check fronius, turn on SSRs etc
};

Sconfig config;



//------------------------------------------------------------------------------
// FLAGS

// group system flags into 1 structure for easy naming.
struct SysFlags
{
  bool restart = 0;
  bool access_point = 0;
  bool update_self = 0;
  bool night = 0;
  bool day = 0;
  bool shutdown_lvolt = 0;
  bool shutdown_hvolt = 0;
  bool update_found = 0;

  bool save_config = 0;

  bool sdcard_read_error = 0;

  bool download_html = 0;

  bool lm75a = 0;

  bool fronius_error = 0; // Fronius 3p Fallback JSON Decode Error:

  bool adc_config_error = 0;
  bool boot_success = 0;

  bool i2c_on = 1;

  bool cells_checked = 0;

  bool ambient_temp = 0;

  bool vapi_checked = 0;

  bool c_pinmode = 0;
  bool i_pinmode = 0;
};

SysFlags flags;

// =================================================================================================

void modeset(byte m = 0, bool manual = 0, uint16_t manual_duration = 0);
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
void loop()
{
  server.handleClient();

  if(check_system_triggers())
    return;

  // ----------------------------------------------------------------------

  check_system_timers();
  set_daynight();
  check_data_sources();

  if(config.dumbsystem)
  {
    return;
  }

  // ----------------------------------------------------------------------
  // ADC Error ?

  if(!config.api_venable[0] && flags.adc_config_error)
  {
    mode_reason = datetime_str(3, '/', ' ', ':') + ": Config ERROR.\nconfig requires ADC, but ADC not found.";

    modeset(0);
    return;
  }




  // ----------------------------------------------------------------------
  // waiting on API ?

  if(config.api_venable[0] && !flags.vapi_checked)
  {
    mode_reason = datetime_str(3, '/', ' ', ':') + ": waiting on first API check.";
    modeset(0);

    return;
  }


  // ----------------------------------------------------------------------
  // Waiting on ADC fist complete poll.

  if(config.monitor_battery && !flags.cells_checked)
  {
    mode_reason = datetime_str(3, '/', ' ', ':') + ": waiting on cells first check";
    modeset(0);

    return;
  }

  // ----------------------------------------------------------------------

  // check if cell volt is low and force update

  if(config.hv_monitor && config.monitor_battery && system_mode == 1 && cell_volt_high > config.battery_volt_max)
  {
    mode_reason = "cell over volt (" + String(cell_volt_high, 3) + "v). force IDLE.";
    log_msg(mode_reason);
    mode_reason = datetime_str(3, '/', ' ', ':') + ": " + mode_reason;

    modeset(0);

    return;
  }

  // check if cell volt is over and force update ?

  if(config.monitor_battery && system_mode == 2 && cell_volt_low <= config.battery_volt_min)
  {
    mode_reason = "Cell under volt (" + String(cell_volt_low, 3) + "v), force IDLE";
    mode_reason = datetime_str(3, '/', ' ', ':') + ": " + mode_reason;

    modeset(0);

    return;
  }


  // ----------------------------------------------------------------------
  // finish loop unless its time to update

  // all checks following happen after min update time.

  if (timers.mode_check > millis())
    return;

  mode_reason = datetime_str(3, '/', ' ', ':') + ": ";


  // ----------------------------------------------------------------------
  // api server issue ?


  if(config.api_venable[0] && vapi_errors >= 10)
  {
    mode_reason += ": API voltage server error.";
    modeset(0);

    return;
  }


  // ----------------------------------------------------------------------
  // environment to hot check
  if(flags.lm75a && board_temp > config.maxsystemtemp)
  {
    String msg = "System Overheat, Ambient Temp " + String(board_temp, 2) + "c, (Max " + String(config.maxsystemtemp, 1) + "c)";

    if(!flags.ambient_temp)
      log_issue(msg);

    flags.ambient_temp = 1;

    mode_reason += msg;

    modeset(0);
    return;
  }

  if(flags.ambient_temp && board_temp + 0.5 > config.maxsystemtemp)
  {
    String msg = "System Cooling Down, Ambient Temp " + String(board_temp, 2) + "c";

    if(board_temp_old != board_temp)
    {
      board_temp_old = board_temp;
      log_msg(msg);
    }
    mode_reason += msg;
    return;
  }

  // if flag set, turn off, log recovery
  if(flags.ambient_temp)
  {
    String msg = "System Overheat recover, Ambient Temp " + String(board_temp, 2) + "c";
    log_issue(msg);
    flags.ambient_temp = 0;
  }


  // ----------------------------------------------------------------------
  // update mode

  if(timeStatus() == timeNotSet)
  {
    mode_reason = "time unsynced";
    return;
  }

  // -------------------------------------------------------------------------
  // IDLE checks

  if
  (
    (!flags.day && !flags.night) || // not day or night
    (!config.i_enable && !config.c_enable) ||   // both devices disabled
    (!config.i_enable && flags.night && !flags.day) ||  // night time only and night time dev disabled
    (!config.c_enable && flags.day && !flags.night)   // day time only and day time dev disabled

  )
  {
    mode_reason += F("Idle (1)\n");
    modeset(0);
    return;
  }

  // -------------------------------------------------------------------------
  // set local flags baed on current mode

  bool finv = 0; // inverter on flag
  bool fchg = 0; // charger on flag

  if(system_mode == 2 || system_mode == 3)
    finv = 1;

  if(system_mode == 1  || system_mode == 3)
    fchg = 1;

  // -------------------------------------------------------------------------
  // Night Device

  mode_reason = datetime_str(3, '/', ' ', ':') + "\n"; // made it this far, so reason will likely be multiline.

  // discharger
  if (config.i_enable && flags.night)
  {
    String new_night_reason = "";
    // LV check
    if (config.monitor_battery && flags.shutdown_lvolt)
    {
      new_night_reason += "IDLE, LV Shutdown\n";
      finv = 0;
    }
    // cooldown check
    else if(timers.inverter_off > millis())
    {
      new_night_reason += "Idle, Inverter Cooldown.\n";
      finv = 0;
    }
    // Prefer DC (enable if !lv and !cooldown
    else if (config.prefer_dc)
    {
      new_night_reason += "Prefer DC\n";
      finv = 1;
    }
    else if (phase_sum > config.night_watts)
    {
      new_night_reason += "Drain\n";
      finv = 1;
    }
    // IDLE
    else if (config.inv_idle_mode && phase_sum < 0 ) // turn off inverter
    {
      new_night_reason += "IDLE (grid " + String(phase_sum,1) + " < 0)\n";
      finv = 0;
    }
    else if (phase_sum < config.night_watts * -1 ) // turn off inverter
    {
      new_night_reason += "IDLE (grid " + String(phase_sum,1) + " < night_watts)\n";
      finv = 0;
    }
    // timer check
    else if (config.night_is_timer)
    {
      new_night_reason += "timer\n";
      finv = 1;
    }
    else if(finv) // no change, inverter still on
    {
      new_night_reason = old_night_reason;
    }
    else // no change, inverter still off
    {
      new_night_reason = "idling\n";
    }

    mode_reason += "Night: " + new_night_reason;
    old_night_reason = new_night_reason;
  }


  // -------------------------------------------------------------------------
  // Day Device

  // charger
  if (config.c_enable && flags.day)
  {
    String new_day_reason = "";

    // idle after min on time check
    if(fchg == 1 && config.c_amot) // check behaviour after being on for min on time. 1 = go to off.
    {
      new_day_reason += "idle after min on time\n";
      fchg = 0;
    }

    // charger cooldown
    else if(timers.charger_off > millis())
    {
      new_day_reason += "charger cooldown\n";
      fchg = 0;
    }

    // timer
    else if (config.day_is_timer)
    {
      new_day_reason += "Timer\n";
      fchg = 1;
    }
    // CHARGE
    else if (phase_sum < (config.day_watts * -1.0) )
    {
      new_day_reason += "Charge\n";
      fchg = 1;
    }
    // IDLE
    else if (phase_sum > 50.0)
    {
      new_day_reason += "idle\n";
      fchg = 0;
    }
    else if(fchg) // no change from prior mode and chg on
    {
      new_day_reason += old_day_reason;
      //new_day_reason += "OLD";
    }
    else // no change from prior mode and chg oFF
    {
      new_day_reason += "idling\n";
    }

    // monitoring voltage charger logic
    // all these checks disable charger if conds met
    if(config.monitor_battery && fchg)
    {
      // HV Shutdown
      if(flags.shutdown_hvolt)
      {
        new_day_reason += "Idle, HV\n";
        fchg = 0;
      }
      // Shutdown
      else if(cell_volt_high > config.battery_volt_max)
      {
        new_day_reason += "Idle, battery full\n";
        fchg = 0;
      }
    }
    mode_reason += "Day: " + new_day_reason;
    old_day_reason = new_day_reason;
  }

  // -------------------------------------------------------------------------
  // Select Mode

  uint8_t tmp_mode = 0;
  if(finv)
    tmp_mode = 2;
  if(fchg)
    tmp_mode = 1;

  if(config.prefer_dc && finv && fchg)
    tmp_mode = 3;

  // SET MODE
  modeset(tmp_mode);
}

// ======================================================================================================================

const unsigned long ap_time = 15 * 60 * 1000;
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

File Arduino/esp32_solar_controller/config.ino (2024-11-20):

// =============================================================================================================================================
// Config Files
// =============================================================================================================================================

void save_config()
{
  Serial.println("Save Conf");

  vars_sanity_check();


  JsonDocument doc;

  doc["fwver"] = FW_VERSION;

  doc["wifi_ssid1"] = config.wifi_ssid1;

  doc["wifi_pass1"] = config.wifi_pass1;
  doc["wifi_ssid2"] = config.wifi_ssid2;
  doc["wifi_pass2"] = config.wifi_pass2;

  doc["hostn"] = config.hostn;

  doc["update_host"] = config.update_host;

  doc["ntp_server"] = config.ntp_server;

  doc["description"] = config.description;

  doc["fronius_push_url"] = config.fronius_push_url;
  doc["3p_direct_url"] = config.threephase_direct_url;

  doc["pub_url"] = config.pub_url;


  for(uint8_t i = 0; i < adsmux.ain_count; i++)
  {
    doc["volt_mod" + String(i+1)] = config.battery_volt_mod[i];
  }

  // API

  for(uint8_t i = 0; i < max_api_vservers; i++)
  {
    String keyname = "api_vserver" + String(i+1);
    doc[keyname] = config.api_vserver_hostname[i];

    keyname = "api_venable" + String(i+1);
    doc[keyname] = config.api_venable[i];
  }

    for(uint8_t i = 0; i < max_api_iservers; i++)
  {
    String keyname = "api_iserver" + String(i+1);
    doc[keyname] = config.api_iserver_hostname[i];

    keyname = "api_ienable" + String(i+1);
    doc[keyname] = config.api_ienable[i];
  }

  doc["api_lm75a"] = config.api_lm75a;
  doc["api_grid"] = config.api_grid;

  // update server count
  config.api_vserver_count = 0;
  for(uint8_t i = 0; i < max_api_vservers; i++)
  {
    if(config.api_venable[i])
      config.api_vserver_count++;
  }



  // END of API

  // PINS
  // note: int8_8t not uint8_t as we use negative numbers for some defaults and pin range isnt higher than 127

  doc["pin_led"]        = (int8_t) config.pin_led;
  doc["pin_charger"]    = (int8_t) config.pin_charger;
  doc["pin_inverter"]   = (int8_t) config.pin_inverter;
  doc["pin_wd"]         = (int8_t) config.pin_wd;
  doc["pin_flash"]      = (int8_t) config.pin_flash;
  doc["pin_sda"]        = (int8_t) config.pin_sda;
  doc["pin_scl"]        = (int8_t) config.pin_scl;

  doc["api_pollsecs"] = config.api_pollsecs;


  // END PINS

  // volts

  doc["pack_volt_min"] = config.pack_volt_min;
  doc["battery_volt_min"] = config.battery_volt_min;
  doc["battery_volt_rec"] = config.battery_volt_rec;
  doc["battery_volt_max"] = config.battery_volt_max;

  doc["cpkwh"] = config.cpkwh;


  // i2c dev char addresses

  doc["oled_addr"] = (uint8_t) config.oled_addr;

  // bools
  doc["prefer_dc"] = (int)config.prefer_dc;

  doc["rotate_oled"] = (int)config.rotate_oled;
  doc["mcptype"] = (int)config.mcptype;
  doc["ads1x15type"] = (int)config.ads1x15type;
  doc["muxtype"] = (int)config.muxtype;


  doc["display_mode"] = (int)config.display_mode;



  doc["dumbsystem"] = (int)config.dumbsystem;

  doc["blink_led"] = (int)config.blink_led;
  doc["blink_led_default"] = (int)config.blink_led_default;
  doc["avg_phase"] = (int)config.avg_phase;
  doc["threephase"] = (int)config.threephase;
  doc["monitor_phase_a"] = (int)config.monitor_phase_a;
  doc["monitor_phase_b"] = (int)config.monitor_phase_b;
  doc["monitor_phase_c"] = (int)config.monitor_phase_c;
  doc["flip_ipin"] = (int)config.flip_ipin;
  doc["flip_cpin"] = (int)config.flip_cpin;
  doc["auto_update"] = (int)config.auto_update;
  doc["serial_off"] = (int)config.serial_off;
  doc["inv_idle_mode"] = (int)config.inv_idle_mode;

  doc["i_enable"] = (int)config.i_enable;
  doc["c_enable"] = (int)config.c_enable;
  doc["day_is_timer"] = (int)config.day_is_timer;

  doc["night_is_timer"] = (int)config.night_is_timer;
  doc["monitor_battery"] = (int)config.monitor_battery;

  doc["hv_monitor"] = (int)config.hv_monitor;


  doc["avg_ain"] = (int)config.avg_ain;


  doc["day_watts"] = config.day_watts;
  doc["night_watts"] = config.night_watts;
  doc["c_start_h"] = config.c_start_h;
  doc["c_finish_h"] = config.c_finish_h;
  doc["i_start_h"] = config.i_start_h;
  doc["i_finish_h"] = config.i_finish_h;

  // sortme

  doc["lv_shutdown_delay"] = config.lv_shutdown_delay;
  doc["hv_shutdown_delay"] = config.hv_shutdown_delay;

  doc["charger_oot_min"] = config.charger_oot_min;
  doc["charger_oot_sec"] = config.charger_oot_sec;
  doc["inverter_oot_min"] = config.inverter_oot_min;
  doc["inverter_oot_sec"] = config.inverter_oot_sec;


  doc["cell_count"] = config.cell_count;
  doc["gmt"] = config.gmt;
  doc["dcvoltage_offset"] = config.dcvoltage_offset;
  doc["board_rev"] = config.board_rev;
  doc["i2cmaxspeed"] = config.i2cmaxspeed;



  doc["webc_mode"] = (int)config.webc_mode;
  doc["led_status"] = (int)config.led_status;

  doc["m247"] = (int)config.m247;
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

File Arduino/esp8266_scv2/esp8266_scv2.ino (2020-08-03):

/*
Esp8266 Solar Controller
by Jacob Jarick, mem.namefix@gmail.com

Arduino ide settings:

 ESP12e module
 - 160mhz
 - Flash Size: 4MB (FS 3MB, OTA ~512kb)
 - v2 higher bandwidth
 - SSL Basic
 - Exceptions Disabled

 ESP 01 / sonoff switch
 - for board use: LOLIN(WEMOS) D1 Mini Lite
 - 160mhz
 - flash size 1mb, 64kb SPIFFS
 - v2 higher bandwidth
 - SSL Basic
 - Exceptions Disabled

 */
#define FW_VERSION 8

#define DAVG_MAGIC_NUM -12345678

// to longer timeout = esp weirdness
#define httpget_timeout 5000

// 10 min
#define check_timeout 600000


#include <Arduino.h>
#include <FS.h>

#include <ESP8266WiFi.h>
#include <ESP8266WiFiMulti.h>
#include <ESP8266HTTPClient.h>

#include <WiFiUdp.h>

#include <ArduinoJson.h>

#include <ESP8266WebServer.h>
#include <ESP8266mDNS.h>
ESP8266WebServer server(80);

#include <ESP8266httpUpdate.h>


// -----------------------------------------------------------------------------------------

#include <Wire.h>
#include "SSD1306Ascii.h"
#include "SSD1306AsciiWire.h"

SSD1306AsciiWire oled;

// -----------------------------------------------------------------------------------------

#include <TimeLib.h>

const unsigned int localPort = 2390;      // local port to listen for UDP packets
const byte NTP_PACKET_SIZE = 48; // NTP time stamp is in the first 48 bytes of the message
byte packetBuffer[NTP_PACKET_SIZE]; //buffer to hold incoming and outgoing packets
WiFiUDP udp;

//------------------------------------------------------------------------------

// #include "EasyBuzzer.h"

//------------------------------------------------------------------------------
// timers

unsigned long update_time = 0;
unsigned long time_since_check = 0;
unsigned long last_update = 0;
unsigned long use_fallback = 0;

unsigned long lv_shutdown_time = 0;
unsigned long hv_shutdown_time = 0;

unsigned long charger_off_time = 0;
unsigned long inverter_off_time = 0;

//------------------------------------------------------------------------------
// FLAGS

bool restart_trigger = 0;
bool ap_mode = 0;
bool self_update = 0;
bool time_synced = 0;
bool night_time = 0;
bool day_time = 0;
bool low_voltage_shutdown = 0;
bool charger_high_voltage_shutdown = 0;
bool high_temp_shutdown = 0;
bool found_update = 0;

//------------------------------------------------------------------------------

const String mime_html    = "text/html";
const String mime_txt     = "text/plain";
const String http_str     = "http://";
const String denied_str   = "Denied";
const String title_str    = "title";

const String dothtml        = ".htm";
const String dottxt        = ".txt";

const String html_config          = "/config" + dothtml;
const String html_timer           = "/timer" + dothtml;
const String html_cpconfig        = "/cpconfig" + dothtml;
const String html_stats           = "/stats" + dothtml;
const String html_mode            = "/mode" + dothtml;
const String html_advance_config  = "/advance" + dothtml;
const String html_footer          = "/footer" + dothtml;
const String html_js_header       = "/jsheader" + dothtml;
const String html_issue_log       = "/issue" + dothtml;
const String html_net_config      = "/network" + dothtml;
const String html_datasrcs        = "/datasrcs" + dothtml;
const String html_sys_info        = "/system" + dothtml;
const String html_upload_config   = "/up_conf" + dothtml;
const String html_port_config     = "/portconf" + dothtml;

const String css_file             = "/style.css";
const String txt_log_system       = "/log" + dottxt;
const String txt_system_messages  = "/msg" + dottxt;
const String txt_passwd_file      = "/passwd";
const String json_config_file     = "/config.jsn";

//------------------------------------------------------------------------------

const byte size_error_msgs = 255;
String error_msgs = "";

float phase_a_watts = 0;
float phase_b_watts = 0;
float phase_c_watts = 0;

float phase_sum = 0;
float phase_sum_old = 0;

float phase_avg = DAVG_MAGIC_NUM;

String passwd = "";

uint8_t download_index = 0; // html page download index
byte system_mode = 0;

// =================================================================================================

uint8_t pin_asel1 = 27;
uint8_t pin_asel2 = 14;
uint8_t pin_asel3 = 26;


//------------------------------------------------------------------------------

#define OPT_DISABLE -2
#define OPT_DEFAULT -1

#define stiny 32
#define ssmall 64
#define smedium 128
#define slarge 256

struct Sconfig
{
  char inverter_url[smedium];
  char inverter_push_url[smedium];
  char meter_url[smedium];
  char update_url[smedium];

  // sortme

  bool download_html;
  uint8_t charger_oot_min;
  uint8_t charger_oot_sec;

  uint8_t inverter_oot_min;
  uint8_t inverter_oot_sec;
  byte gmt; // divide by 2 and minus 12
  uint8_t board_rev;

  // wifi

  char wifi_ssid1[ssmall];
  char wifi_pass1[ssmall];
  char wifi_ssid2[ssmall];
  char wifi_pass2[ssmall];

  char hostn[stiny];

  int8_t pin_led;
  int8_t pin_charger;
  int8_t pin_inverter;
  int8_t pin_wd;
  int8_t pin_flash;

  int8_t pin_sda;
  int8_t pin_scl;

  char update_host[ssmall];

  char ntp_server[ssmall];
  char description[smedium];

  // device addresses

  char oled_addr;
  char pcf857a_addr;

  // bools

  bool rotate_oled;
  bool button_timer_mode;
  bool blink_led;
  bool blink_led_default;
  bool avg_phase;
  bool threephase;
  bool monitor_phase_a;
  bool monitor_phase_b;
  bool monitor_phase_c;
  bool flip_ipin;
  bool flip_cpin;
  bool auto_update;
  bool wifi_highpower_on;
  bool i_enable;
  bool c_enable;
  bool day_is_timer;
  bool night_is_timer;
  //
  int day_watts;
  int night_watts;

  uint8_t button_timer_secs;
  uint8_t button_timer_max;
  uint8_t c_start_h;
  uint8_t c_finish_h;
  uint8_t i_start_h;
  uint8_t i_finish_h;

  bool webc_mode;
  bool led_status;
};

Sconfig config;

// =================================================================================================
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

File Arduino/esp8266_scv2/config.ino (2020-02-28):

// =============================================================================================================================================
// Config Files
// =============================================================================================================================================

void save_config()
{
  Serial.println("Save Conf");

  vars_sanity_check();


  DynamicJsonDocument doc(2500);

  doc["wifi_ssid1"] = config.wifi_ssid1;

  doc["wifi_pass1"] = config.wifi_pass1;
  doc["wifi_ssid2"] = config.wifi_ssid2;
  doc["wifi_pass2"] = config.wifi_pass2;

  doc["hostn"] = config.hostn;

  doc["update_host"] = config.update_host;

  doc["ntp_server"] = config.ntp_server;

  doc["description"] = config.description;



  doc["inverter_url"] = config.inverter_url;
  doc["inverter_push_url"] = config.inverter_push_url;
  doc["meter_url"] = config.meter_url;
  doc["update_url"] = config.update_url;

//   doc[""] = config.;

  // PINS

  doc["pin_led"] = config.pin_led;
  doc["pin_charger"] = config.pin_charger;
  doc["pin_inverter"] = config.pin_inverter;
  doc["pin_wd"] = config.pin_wd;
  doc["pin_flash"] = config.pin_flash;
  doc["pin_sda"] = config.pin_sda;
  doc["pin_scl"] = config.pin_scl;

  // END PINS

  // floats


  // ints

  // i2c dev char addresses

  doc["oled_addr"] = config.oled_addr;
  doc["pcf857a_addr"] = config.pcf857a_addr;

  // bools
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

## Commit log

2020-02-28 source push
    [led controller v5-B_Cu.gbr, led controller v5-B_Mask.gbr, led controller v5-B_Paste.gbr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]
2020-02-29 Create esp32 board.png
2020-03-02 adc code, html examples
2020-03-02 fixes to support latest esp32 arduino release.
    adc - set gain etc after inlcude ads11115
    ESP32HTTPUpdate - old httpupdate no longer works, fixes applied.
    maths - float_max - ESP32HTTPUpdate (among others) undef Arduino min and max. easiest fix is to provide my own function.
    webpages - toDouble not a string member anymore ? or never was. fixed.
    HTTPClient - argument syntax has changed for esp32 lib - fixed.
    [adc.ino, config.ino, esp32_solar_controller.ino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]
2020-03-03 update.ino - fix html loop if unable to fetch file
    [update.ino]
2020-03-06 i2c is buggy on latest board. slowed down bus speed
    [esp32_solar_controller.ino, i2c_scanner.ino, oled_helper.ino]
2020-03-07 adc battery fix
2020-03-07 update logic, adc, ports, save config optimization
2020-03-13 battery calibration
2020-03-15 battery + temp
    battery calibration page added.
    ntc temp max changed to uint8_t
2020-03-16 24/7 mode added
    same as setting charger and inverter time slots to 12-12
2020-03-16 battery calibrate JS moved to battery page
2020-03-16 updated ESP32 board
    [9p-parallel-fused-B_Cu.gbl, 9p-parallel-fused-B_Cu.gbr, 9p-parallel-fused-B_Mask.gbr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]
2020-03-16 Update esp32_solar_controller.ino
    24/7 - idle between device swaps.
    mode reason message text cleaned up
    [esp32_solar_controller.ino]
2020-03-16 remove all traces of frline
    handy for esp8266 due to lack of progmem space, for esp32 it just makes things harder to follow.
2020-03-31 battery_msg removed.
2020-04-09 adc polling
    much more efficient ADC checking.
2020-04-09 adc poll timer
2020-04-09 rm volt_synced flag
2020-04-09 phase voltage monitoring
2020-04-10 adc_enable
    skip ADC reads on disabled channels
    [adc.ino, config.ino, esp32_solar_controller.ino]
2020-04-12 removed battery_volt_idl & battery_volt_over
2020-05-18 arduino JSON lib update
2020-08-03 micro board. esp8266 firmware refresh
2020-08-17 led, stats
    fixed led modes.
    added energy display options.
    [esp32_solar_controller.ino, webpages.ino]
2020-09-03 ADC checks
    if monitor temp or voltage enabled and ADC not found force IDLE.
2020-09-11 div by 0 fix
    [config.ino, esp32_solar_controller.ino, fronius.ino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]
2020-10-21 ADC tweak
2020-11-24 min off time.
    mainly code to support my bore pump.
2021-01-13 swapped to common header
    [esp32_solar_controller.ino, update.ino, webpages.ino]
2021-09-23 fw 228.
    had to roll back o esp32 board libs 1.0.6 - issue with SD card in 2.0.0
    [esp32_solar_controller.ino]
2021-10-13 JSON config pretty print.
    Pub update dir.
2021-10-29 fixes, single phase updates.
    get_watts - should work with single phase better
    calc_energy_usage - uses its own timer.
    [config.ino, esp32_solar_controller.ino, fronius.ino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]
2021-11-09 fw 247
    mostly white space fixes
    [esp32_solar_controller.ino, webpages.ino]
2021-11-11 voltage tracking
2021-11-11 fix min AC voltage tracking
    [esp32_solar_controller.ino, fronius.ino]
2021-11-20 adc mux code update complete..
    backwards compatible with v3 board mux.
    must set ADS1x15type and MUXType in system settings.
2021-11-24 optimize adc mux polling code
2021-11-24 BUGFIX - pin select in adc poll was wonky
    [esp32_solar_controller.ino]
2021-11-25 adc code tweaks. esp board libs 2.0.1
2021-11-26 roll back to 1.0.6 of esp32 board libs
    issues with SPI and SD card
    [esp32_solar_controller.ino, webpages.ino]
2021-12-02 adc reads speed up
2021-12-10 code cleanup
    update functions no longer return strings. (yuck)
    [esp32_solar_controller.ino, update.ino, webpages.ino]
2022-01-19 log overheat and recovery
    [esp32_solar_controller.ino]
2022-01-21 track min max amb temp
2022-01-26 correct local library refs
    [esp32_solar_controller.ino]
2022-01-27 377 - pack_total_volts fixup
    [adc.ino, esp32_solar_controller.ino]
2022-01-30 adc poll tweaks
2022-01-31 fix absent fronius_push_url from config
    also renamed since I broke it in the config anyway.
    [config.ino, esp32_solar_controller.ino, fronius.ino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]
2022-02-20 batcal for precision board
2022-08-16 Update esp32 board.png
2023-03-31 clean compile on latest versions of esp32 base and arduinojson
    also had to patch lm75a lib
2023-04-22 NTP update
    also lib & board update
2023-04-25 added switch for HASS
2023-04-25 expose pin mode in api
2023-05-19 esp32 board fw update, html fix
    [esp32_solar_controller.ino]
2024-11-18 migrate to board libs 3.0
    pwm fixed
    [esp32_solar_controller.ino, pwm.ino]
2024-11-18 Updating to boards library 3.0
    AP Mode Fixed
    [esp32_solar_controller.ino, reset_reason.ino, wifi.ino]
2024-11-20 no longer using DynamicJsonDocument
    was a straight swap from DynamicJsonDocument to JsonDocument
    just had to remove the config_json_size
    [apiclient.ino, config.ino, fronius.ino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]
